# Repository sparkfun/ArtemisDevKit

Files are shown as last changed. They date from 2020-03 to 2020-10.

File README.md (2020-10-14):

SparkFun Artemis Development Kit
========================================

SparkFun Artemis Development Kit (https://www.sparkfun.com/products/16828)

* [*SparkFun Artemis Development Kit (DEV-16828)*](https://www.sparkfun.com/products/16828)
* [*SparkFun Artemis Development Kit with Camera (KIT-17071)*](https://www.sparkfun.com/products/17071)

The [*SparkFun Artemis Development Kit (DEV-16828)*](https://www.sparkfun.com/products/16828) is the latest board to be released around the SparkFun Artemis Module and it allows access to more software development features than previous Artemis based boards. Recommended software used to program the Artemis DK are the Arduino IDE, Arm® Mbed™ OS (Studio and CLI), and AmbiqSDK. An updated USB interface (MKL26Z128VFM4 Arm® Cortex®-M0+ MCU, from NXP) allows the Artemis Dev Kit to act as:

* Mass Storage Device (MSD): Used to provide drag and drop programming to the Artemis Module.
* Human Interface Device (HID): Used for the debugging interface to the Artemis Module.
* Communication Port (COM): Used to provide a serial communication UART between the Artemis and the USB connection (PC).

Repository Contents
-------------------

* **/Hardware**
   * Eagle design files (.brd, .sch)
   * Dimensions (.pdf and .png)
   * **/Production** - Production panel files (.brd)
* **/Reference**
   * Datasheets (.pdf)
   * Functional Block Digaram (.png)

Documentation
--------------
* [Hardware Getting Started Guide](https://learn.sparkfun.com/tutorials/1198) - Basic Hardware Guide for the Artemis DK
* Software Guides:
    * [Artemis Development with the Arduino IDE](https://learn.sparkfun.com/tutorials/artemis-development-with-the-arduino-ide) - A software guide for developing with the Artemis module (and related boards) in the Arduino IDE
    * [Artemis Development with Arm&reg; Mbed&trade; OS (Beta)](https://learn.sparkfun.com/tutorials/artemis-development-on-arm-mbed-os-beta) - A software pre-release guide to get started developing in with Mbed&trade; OS
    * Artemis Development with Arm&reg; Mbed&trade; OS (Pending release)
    * [Artemis Development with the AmbiqSDK](https://learn.sparkfun.com/tutorials/using-sparkfun-edge-board-with-ambiq-apollo3-sdk) - A software guide for utilizing the SparkFun Edge board with the AmbiqSDK
* [GitHub Repository for Apollo3 Board Support Packages (BSP)](https://github.com/sparkfun/SparkFun_Apollo3_AmbiqSuite_BSPs) - The Board Support Packages (BSPs) for SparkFun Apollo3 (Artemis) based boards to be used in the AmbiqSuite SDK
    * [ DAPLink Bootloader: `kl26z_artemis_dk_if.bin`](https://github.com/sparkfun/SparkFun_Apollo3_AmbiqSuite_BSPs/raw/master/artemis_dk/intfc/kl26z_bl.bin) - Underlying *bootloader* firmware for the MKL26Z MCU
    * [DAPLink Interface Firmware: `kl26z_bl.bin`](https://github.com/sparkfun/SparkFun_Apollo3_AmbiqSuite_BSPs/raw/master/artemis_dk/intfc/kl26z_artemis_dk_if.bin) - The accompanying *interface firmware* for the DAPLink debug probes from the MKL26Z to the target Artemis Module
* Development Software:
    * [SparkFun Ambiq Apollo3 Arduino Core](https://github.com/sparkfun/Arduino_Apollo3) - The SparkFun Arduino core for the Apollo3 MCU (i.e. the Artemis modules)
        * `.json` file needed for the SparkFun Ambiq Apollo3 Arduino Core:
        <br>
            <code><a href="https://raw.githubusercontent.com/sparkfun/Arduino_Apollo3/master/package_sparkfun_apollo3_index.json">https://raw.githubusercontent.com/sparkfun/Arduino_Apollo3/master/package_sparkfun_apollo3_index.json</a></code>
    * [Mbed™ OS](https://github.com/sparkfun/mbed-os-ambiq-apollo3) - Implementation of the Apollo3 (i.e. Artemis module) in Mbed&trade; OS
    * [AmbiqSDK](https://github.com/sparkfun/AmbiqSuiteSDK) - A copy of the AmbiqSuite SDK maintained by SparkFun
    * [pyOCD](https://github.com/sparkfun/pyOCD) - Implementation of the Apollo3 (i.e. Artemis module) for pyOCD
* Arduino Libraries:
    * [SparkFun LIS2DH12 Arduino Library](https://github.com/sparkfun/SparkFun_LIS2DH12_Arduino_Library) - The Arduino library for the accelerometer
    * [ArduinoBLE Library](https://github.com/arduino-libraries/ArduinoBLE) - The Arduino library for the BLE support

Product Versions
----------------
* [*SparkFun Artemis Development Kit with Camera (KIT-17071)*](https://www.sparkfun.com/products/17071) - v1.0 Initial Release *(kitted with Himax Camera)*
* [*SparkFun Artemis Development Kit (DEV-16828)*](https://www.sparkfun.com/products/16828) - v1.0 Initial Release

License Information
-------------------

This product is _**open source**_! 

Please review the LICENSE.md file for license information. 

If you have any questions or concerns on licensing, please contact technical support on our [SparkFun forums](https://forum.sparkfun.com/viewforum.php?f=152).

Distributed as-is; no warranty is given.

- Your friends at SparkFun.

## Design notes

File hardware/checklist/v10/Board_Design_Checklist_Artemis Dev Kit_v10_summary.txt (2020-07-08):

1) Does the board pass the Board Autochecklist ULP? [NO]
comment: footprint silk for SWD connectors, no standoffs (intentional), header spacing check is thrown off by addtl. PTH headers

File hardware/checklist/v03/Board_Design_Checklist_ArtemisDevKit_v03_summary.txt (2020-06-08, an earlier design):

1) Are the standoffs in the lower right corner? [NO]
comment: This design has no standoffs (could change for Reds)

2) Does the board pass the Board Autochecklist ULP? [NO]
comment: fails on standoffs (intentional), breadboard spacing (intentional, and not totally accurate) and footprint silk width (eagle library needs updating)

3) Do V-Scored edges have a 50 mil border free of pads and parts (to prevent cracking on separation)? [NO]
comment: This is outdated. We routinely have pads within 50 mil of edges

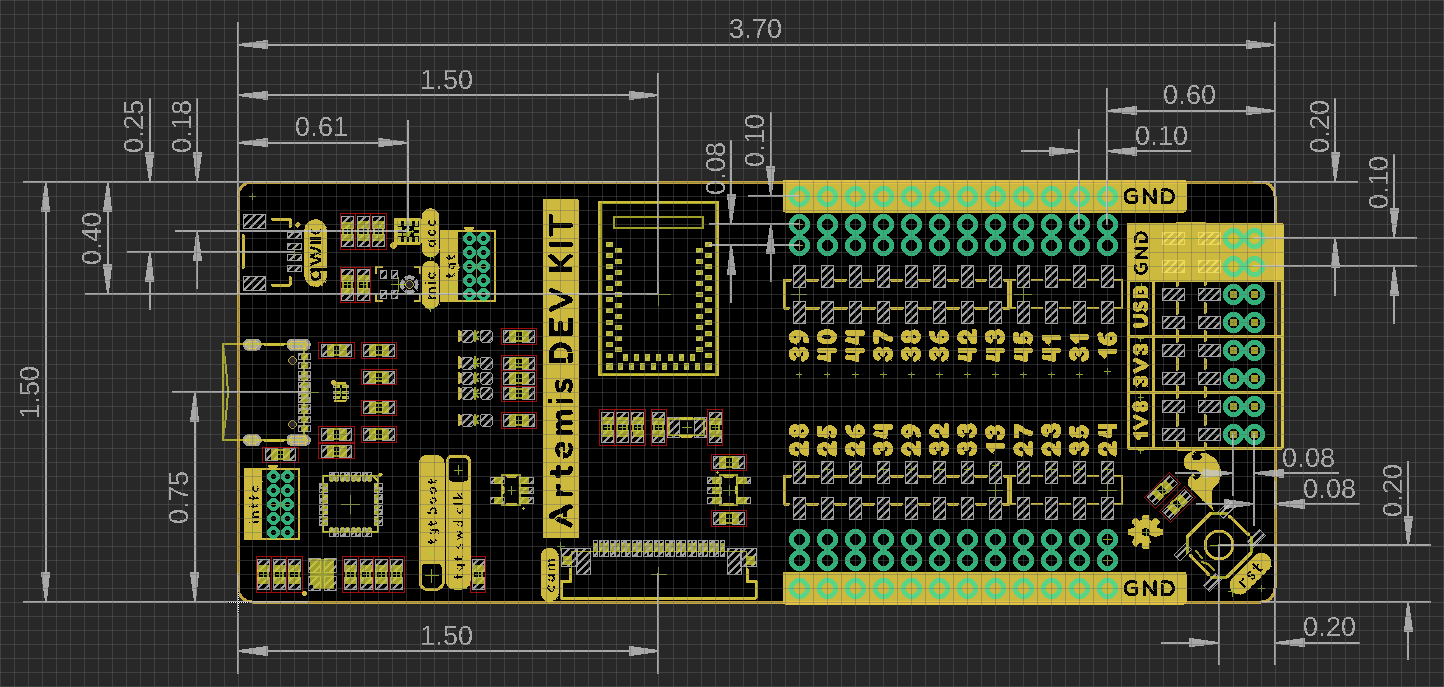
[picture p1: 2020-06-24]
hardware/board_dimensions.PNG

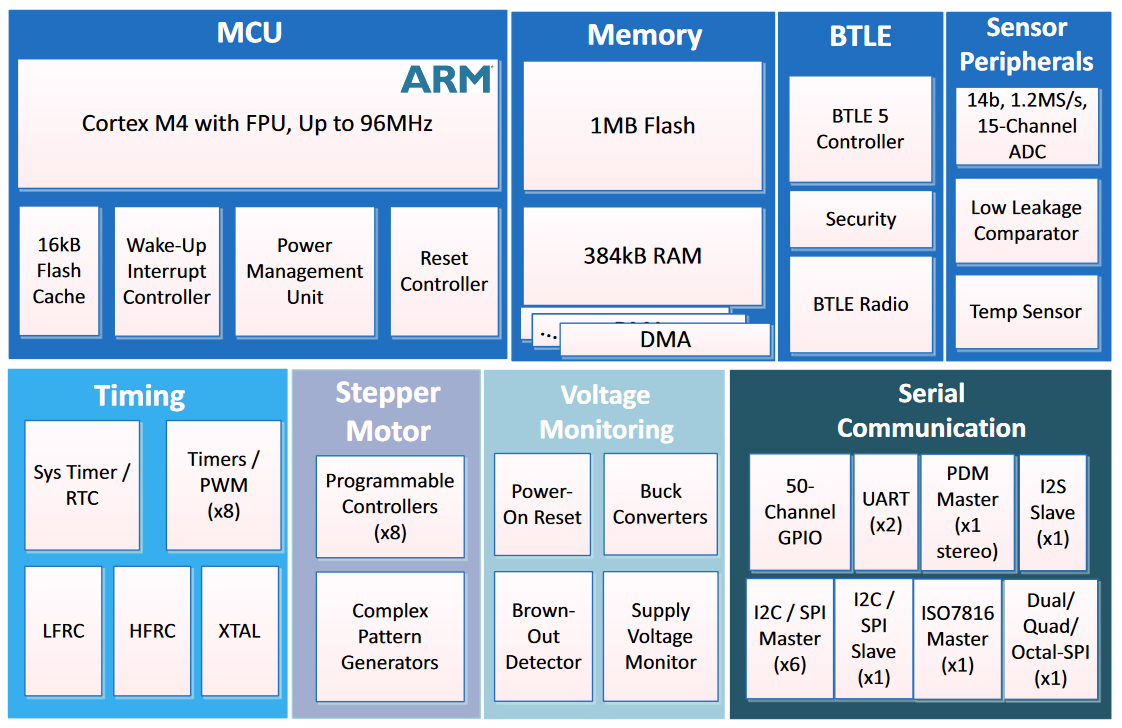
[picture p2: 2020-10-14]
reference/MCU_system_block_diagram.PNG

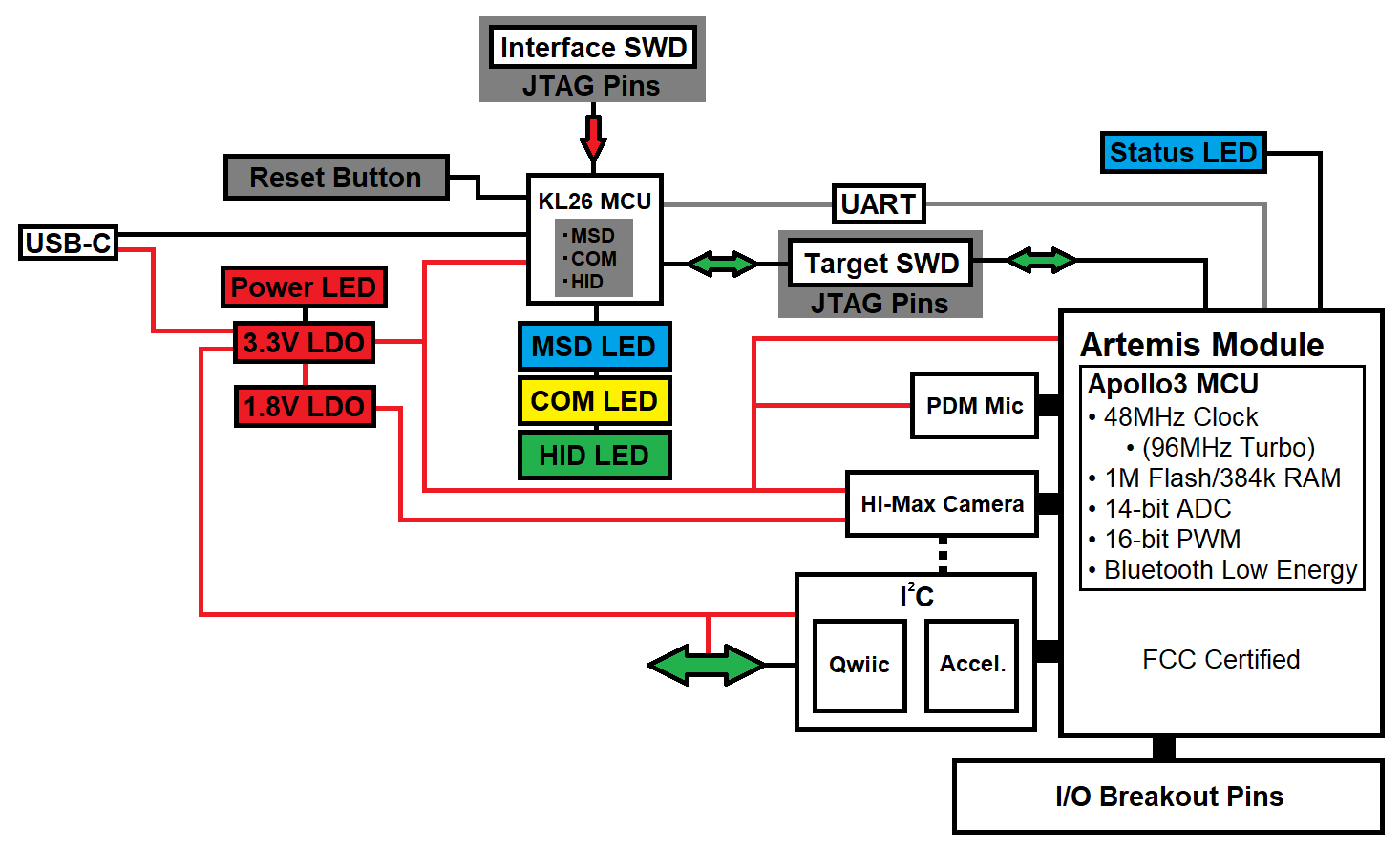
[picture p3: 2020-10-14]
reference/board_functional_block_diagram.png

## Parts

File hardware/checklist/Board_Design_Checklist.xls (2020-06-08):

SECTION | CHECK | STATUS | DEPENDANCY | CORRECT ANSWER | USER | USER-ANSWER | COMMENT | WIKI_LINK
Macro | is_revision | 0
Macro | has_pth | 0
Macro | has_i2c | 0
Macro | has_SPI | 0
Macro | has_1x6_ftdi_header | 0
Macro | has_jumpers | 0
Macro | has_leds | 0
Macro | has_vreg | 0
Macro | has_QFN | 0
Macro | has_SS | 0
Macro | has_multi_sheet | 0
Macro | is_kit | 0
Macro | has_serial | 0
Macro | is_4layer | 0
Macro | has_milling | 0
Macro | has_switchorbutton | 0
Macro | has_collaboration | 0
Schematic | Does the board pass the Schematic Autochecklist ULP? |  |  | YES
Schematic | Are all schematic objects inside the frame? |  |  | YES
Schematic | Is proper attribution given to the original designer? |  |  | YES
Schematic | Is "Revised by: " and the reviser's name present? |  | 2 | YES
Schematic | Have all nets been drawn straight out from pin connections at least one grid space? |  |  | YES
Schematic | Are there any 4-way junctions? |  |  | NO
Schematic | Are junction dots used for all 3-wire connections? |  |  | YES
Schematic | Are the fiducials in the lower right corner? |  |  | YES
Schematic | Are the standoffs in the lower right corner? |  |  | YES
Schematic | Are dashed grey lines ('info' eagle layer 97) used to clearly separate different areas? |  |  | YES
Schematic | Is the version number correct? |  |  | YES
Schematic | Is the version number included on all sheets? |  | 12 | YES
Schematic | Do all GND connections use the GND symbol (oriented downward)? |  |  | YES
Schematic | Do all VCC connections use the VCC symbol (oriented upward)? |  |  | YES
Schematic | Is the VCC range clearly labeled? |  |  | YES
Schematic | Are any jumpers labeled clearly by their function and possible settings? |  | 7 | YES
Schematic | Are any appropriate warnings (voltage conversion, sensitive I/O) labeled? |  |  | YES
Schematic | Are any notes of two versions of the board in the schematic (3.3V regulator vs 5V regulator)? |  |  | YES
Schematic | Do any part names have '/.~' in them? (Multiple sheets) |  | 12 | NO
Schematic | Have you verified that the BOM *including PCB* (also checking for PROD_ID, NAME, VALUE, PREFIX)? |  |  | YES
Schematic | Do any parts have unnecessary values (Eagle has autoset the package as the value)? |  |  | NO
Schematic | Regarding the voltage regulator, is the input on the LEFT, and the output on the RIGHT? |  | 9 | YES
Schematic | Is the I2C address in the schematic? |  | 4 | YES
Schematic | Is the I2C pin order correct (GND/VCC/SDA/CLK) and did you consider using a Qwiic connector? |  | 4 | YES |  |  |  | https://wiki.sparkfun.com/index.php?title=Eagle_Rules#Pin_Out.2FConnection_Orientation
Schematic | Is the I2C pull-up resistor isolation jumper present? |  | 4 | YES |  |  |  | https://wiki.sparkfun.com/index.php?title=Eagle_Rules#Component_Placement
Schematic | Is the SPI pull-up resistor for Chip Select present? |  | 5 | YES |  |  |  | https://wiki.sparkfun.com/index.php?title=Eagle_Rules#Component_Placement
Schematic | Is the MISO tri-state buffer included? |  | 5 | YES |  |  |  | https://wiki.sparkfun.com/index.php?title=Eagle_Rules#Component_Placement
Board | Does the board pass the Board Autochecklist ULP? |  |  | YES |  |  |  | https://wiki.sparkfun.com/index.php?title=Qwiic_Standard
Board | If this board is not branded as a Qwicc board, but contains a Qwiic connector, is the connector labeled with “QWIIC” text silk? |  | 4 | YES
Board | Are the inner layers on the correct eagle layers? (2 and 15) |  | 15 | YES |  |  |  | https://wiki.sparkfun.com/index.php?title=Eagle_Rules#Board_Creation.2C_Outline
Board | Does your 4 layer board include '1' '2' '3' '4' in the copper of each layer? |  | 15 | YES |  |  |  | https://wiki.sparkfun.com/index.php?title=Eagle_Rules#Board_Creation.2C_Outline
Board | If this is a Qwiic board, does it follow the design guidelines for Qwiic boards in the Wiki? |  | 4 | YES |  |  |  | https://wiki.sparkfun.com/index.php?title=Eagle_Rules#Board_Creation.2C_Outline
Board | If this requires very precise dimensions (e.g. USB stick), did you consider GP's tolerances? (dimension=5mils, Vscore=10mils) |  |  |  |  |  |  | https://wiki.sparkfun.com/index.php?title=Eagle_Rules#Fab_house_Tolerances
Board | Do all testpoints have a separation of at least 0.1 inch (preferably placed on a 0.05 inch grid)? |  |  | YES |  |  |  | https://wiki.sparkfun.com/index.php?title=Eagle_Rules#Board_Creation.2C_Outline
Board | Can standoffs/screws be used clear of other parts? |  |  | YES |  |  |  | https://wiki.sparkfun.com/index.php?title=Eagle_Rules#Board_Creation.2C_Outline
Board | Is the FTDI connector accessible (do neighboring parts allow enough space to clear each side)? |  | 6 | YES |  |  |  | https://wiki.sparkfun.com/index.php?title=Eagle_Rules#Pin_Out.2FConnection_Orientation
Board | Is the FTDI connector oriented so the FTDI breakout can be slid on properly (IC side up, header side down)? |  | 6 | YES |  |  |  | https://wiki.sparkfun.com/index.php?title=Eagle_Rules#Pin_Out.2FConnection_Orientation
Board | Are vias tented correctly? |  |  | YES |  |  |  | https://wiki.sparkfun.com/index.php?title=Eagle_Rules#Trace_Routing.2C_Polygon_Pours.2C_and_Vias
Board | If possible, are all overhanging parts on the same edge of the board (this helps with panelization)? |  |  | YES |  |  |  | https://wiki.sparkfun.com/index.php?title=Eagle_Rules#Pin_Out.2FConnection_Orientation
Board | If this design requires special ordering or production assembly instructions, have the symbols/packages been added with notes? (PCB thickness, humidity sensitivity, etc.) |  |  | YES
Board | Are any vias intended to be used as PTH headers (they shouldn't be)? |  |  | NO |  |  |  | https://wiki.sparkfun.com/index.php?title=Eagle_Rules#Trace_Routing.2C_Polygon_Pours.2C_and_Vias
Board | Is the LED color standard followed? (red for power, blue for STAT, green for TX, yellow for RX) |  | 8 | YES |  |  |  | https://wiki.sparkfun.com/index.php?title=Eagle_Rules#Component_Placement
Board | Do parts that need selective solder have a planned nozzle path on layer 48? (valid widths: 0.178", 0,263", 0.354") |  | 11 | YES |  |  |  | https://wiki.sparkfun.com/index.php?title=Eagle_Rules#Selective_Soldering
Board | As best as possible, do all SMD pads have only 1 trace entering the pad? |  |  | YES |  |  |  | https://wiki.sparkfun.com/index.php?title=Eagle_Rules#PCB_Layout
Board | Are there any natural bridges on SMT components? |  |  | NO |  |  |  | https://wiki.sparkfun.com/index.php?title=Eagle_Rules#PCB_Layout
Board | Do V-Scored edges have a 50 mil border free of pads and parts (to prevent cracking on separation)? |  |  | YES
Board | Is the direction of TX/RX serial connections correct? |  | 14 | YES
Board | Are the TX/RX pins of the FTDI properly connected? |  | 6 | YES
Board | Is trace routing up to spec? (to/from center-points, straight lines, 45 angles, 'T' intersections, no right angles or acid traps) |  |  | YES |  |  |  | https://wiki.sparkfun.com/index.php?title=Eagle_Rules#PCB_Layout
Board | For thermal considerations, are traces routed away from the component, with symmetrical routing? |  | 10 | YES
Board | Do all footprints pass 1:1 check? (Applies mostly to new components) |  |  | YES
Board | Are all QFN components with 6 or more leads 75 percent pasted on lead pads? (May be contended depending on performance) |  | 10 | YES |  |  |  | https://wiki.sparkfun.com/index.php?title=Eagle_Rules#Footprints.2FPackages
Board | Are center pad cream apertures properly reduced? (50-75% paste is good) |  | 10 | YES |  |  |  | https://wiki.sparkfun.com/index.php?title=Eagle_Rules#Footprints.2FPackages
Board | Is there solder mask between pads on of 11 mil separation and greater? |  |  | YES |  |  |  | https://wiki.sparkfun.com/index.php?title=Eagle_Rules#Fab_house_Tolerances
Board | Is there a correct version number in the copper (aligned properly with the edge of the PCB)? |  |  | YES
Board | Does it pass DRC with top/bottom keepout layers on? |  |  | YES
Board | If there are any DRC errors, have they all been approved? |  |  | YES
Board | Are all KIT PTH parts on the correct side with correct masking (e.g. the TSTOP or BSTOP expose the correct side) |  | 13 | YES
Documentation | Is there a note for a 4-layer board (on tDOCU)? |  | 15 | YES
Documentation | Do all packages have NAME and VALUE? |  |  | YES
Documentation | Is there a note for a board thickness other than 0.63 inch?
Documentation | Are measurements included for outer dimension and standoffs (Eagle layer 47)? |  |  | YES
Documentation | Are the board dimensions on 0.05 inch or 0.01 inch grid? |  |  | YES
Documentation | Are routed-out areas labeled 'ROUTE OUT' (on dimension)? |  | 16 | YES
Documentation | Is the designer name included in tDocu? |  |  | YES
Documentation | Is 'Revised by:' and 'Revisor Name' included in tDocu? |  | 2 | YES
Documentation | Are all Fuse Bits/ Lock Bits/ Config Words etc documented on the Github Readme? |  |  | YES
Silkscreen/Labeling | Is the name of the board on the board? |  |  | YES |  |  |  | https://wiki.sparkfun.com/index.php?title=Eagle_Rules#PCB_Silk
Silkscreen/Labeling | Are all LEDs labeled with their purpose? |  | 8 | YES
Silkscreen/Labeling | Are all PTHs (aka connectors) clearly labeled with their purpose on both sides of the board? |  |  | YES
Silkscreen/Labeling | Are battery terminals labeled +/- correctly? |  |  | YES
Silkscreen/Labeling | Are all jumpers labeled? |  | 7 | YES
Silkscreen/Labeling | If it is a 3-way jumper, is there a label on each side of the jumper? |  | 7 | YES
Silkscreen/Labeling | Are all switches/buttons labeled properly? |  | 17 | YES
Silkscreen/Labeling | Are active low pins labeled clearly? |  |  | YES
Silkscreen/Labeling | Are all labels lined up properly and legible? |  |  | YES
Silkscreen/Labeling | Does the FTDI connector have BLK/GRN labeled correctly? |  | 6 | YES
Silkscreen/Labeling | Do all components have polarity or pin 1 labeled? |  |  | YES
Silkscreen/Labeling | Is the polarity label outside of the package for visibility after part population? |  |  | YES
Silkscreen/Labeling | Are there check labels for different versions of the board (3.3V vs 5V)? |  |  | YES
Silkscreen/Labeling | Is the firmware opensource? If not, did you omit the OSHW Logo? |  | 18 | YES
Silkscreen/Labeling | Is any silkscreen overlaid on vias? |  |  | NO
Silkscreen/Labeling | Is there a URL for any kits or unique boards?
Special | Are dimension lines properly spaced for V-scoring (lines on a 0.020” center-to-center spacing)?
Special | On white solder mask pcbs, is there any solder mask between leads on large SMT components?
Special | Are axes labeled correctly?
Special | Are there warning labels for high voltage areas?
END | Thanks for flying with us. Have a great day!!

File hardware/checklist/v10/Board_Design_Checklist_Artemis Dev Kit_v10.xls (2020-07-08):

SECTION | CHECK | STATUS | DEPENDANCY | CORRECT ANSWER | USER | USER-ANSWER | COMMENT | WIKI_LINK
Macro | is_revision | 0
Macro | has_pth | 0
Macro | has_i2c | 1
Macro | has_SPI | 1
Macro | has_1x6_ftdi_header | 0
Macro | has_jumpers | 1
Macro | has_leds | 1
Macro | has_vreg | 1
Macro | has_QFN | 0
Macro | has_SS | 0
Macro | has_multi_sheet | 0
Macro | is_kit | 0
Macro | has_serial | 1
Macro | is_4layer | 0
Macro | has_milling | 0
Macro | has_switchorbutton | 1
Macro | has_collaboration | 1
Schematic | Does the board pass the Schematic Autochecklist ULP? |  |  | YES | Lyocek | YES
Schematic | Are all schematic objects inside the frame? |  |  | YES | Lyocek | YES
Schematic | Is proper attribution given to the original designer? |  |  | YES | Lyocek | YES
Schematic | Is "Revised by: " and the reviser's name present? |  | 2 | YES | Lyocek | *n/a*
Schematic | Have all nets been drawn straight out from pin connections at least one grid space? |  |  | YES | Lyocek | YES
Schematic | Are there any 4-way junctions? |  |  | NO | Lyocek | NO
Schematic | Are junction dots used for all 3-wire connections? |  |  | YES | Lyocek | YES
Schematic | Are the fiducials in the lower right corner? |  |  | YES | Lyocek | YES
Schematic | Are the standoffs in the lower right corner? |  |  | YES | Lyocek | n/a
Schematic | Are dashed grey lines ('info' eagle layer 97) used to clearly separate different areas? |  |  | YES | Lyocek | YES
Schematic | Is the version number correct? |  |  | YES | Lyocek | YES
Schematic | Is the version number included on all sheets? |  | 12 | YES | Lyocek | *n/a*
Schematic | Do all GND connections use the GND symbol (oriented downward)? |  |  | YES | Lyocek | YES
Schematic | Do all VCC connections use the VCC symbol (oriented upward)? |  |  | YES | Lyocek | YES
Schematic | Is the VCC range clearly labeled? |  |  | YES | Lyocek | YES
Schematic | Are any jumpers labeled clearly by their function and possible settings? |  | 7 | YES | Lyocek | YES
Schematic | Are any appropriate warnings (voltage conversion, sensitive I/O) labeled? |  |  | YES | Lyocek | n/a
Schematic | Are any notes of two versions of the board in the schematic (3.3V regulator vs 5V regulator)? |  |  | YES | Lyocek | n/a
Schematic | Do any part names have '/.~' in them? (Multiple sheets) |  | 12 | NO | Lyocek | *n/a*
Schematic | Have you verified that the BOM *including PCB* (also checking for PROD_ID, NAME, VALUE, PREFIX)? |  |  | YES | Lyocek | YES
Schematic | Do any parts have unnecessary values (Eagle has autoset the package as the value)? |  |  | NO | Lyocek | NO
Schematic | Regarding the voltage regulator, is the input on the LEFT, and the output on the RIGHT? |  | 9 | YES | Lyocek | YES
Schematic | Is the I2C address in the schematic? |  | 4 | YES | Lyocek | n/a
Schematic | Is the I2C pin order correct (GND/VCC/SDA/CLK) and did you consider using a Qwiic connector? |  | 4 | YES | Lyocek | YES |  | https://wiki.sparkfun.com/index.php?title=Eagle_Rules#Pin_Out.2FConnection_Orientation
Schematic | Is the I2C pull-up resistor isolation jumper present? |  | 4 | YES | Lyocek | n/a |  | https://wiki.sparkfun.com/index.php?title=Eagle_Rules#Component_Placement
Schematic | Is the SPI pull-up resistor for Chip Select present? |  | 5 | YES | Lyocek | n/a |  | https://wiki.sparkfun.com/index.php?title=Eagle_Rules#Component_Placement
Schematic | Is the MISO tri-state buffer included? |  | 5 | YES | Lyocek | n/a |  | https://wiki.sparkfun.com/index.php?title=Eagle_Rules#Component_Placement
Board | Does the board pass the Board Autochecklist ULP? |  |  | YES | Lyocek | NO | footprint silk for SWD connectors, no standoffs (intentional), header spacing check is thrown off by addtl. PTH headers | https://wiki.sparkfun.com/index.php?title=Qwiic_Standard
Board | If this board is not branded as a Qwicc board, but contains a Qwiic connector, is the connector labeled with “QWIIC” text silk? |  | 4 | YES | Lyocek | YES
Board | Are the inner layers on the correct eagle layers? (2 and 15) |  | 15 | YES | Lyocek | *n/a* |  | https://wiki.sparkfun.com/index.php?title=Eagle_Rules#Board_Creation.2C_Outline
Board | Does your 4 layer board include '1' '2' '3' '4' in the copper of each layer? |  | 15 | YES | Lyocek | *n/a* |  | https://wiki.sparkfun.com/index.php?title=Eagle_Rules#Board_Creation.2C_Outline
Board | If this is a Qwiic board, does it follow the design guidelines for Qwiic boards in the Wiki? |  | 4 | YES | Lyocek | n/a |  | https://wiki.sparkfun.com/index.php?title=Eagle_Rules#Board_Creation.2C_Outline
Board | If this requires very precise dimensions (e.g. USB stick), did you consider GP's tolerances? (dimension=5mils, Vscore=10mils) |  |  |  | Lyocek | n/a |  | https://wiki.sparkfun.com/index.php?title=Eagle_Rules#Fab_house_Tolerances
Board | Do all testpoints have a separation of at least 0.1 inch (preferably placed on a 0.05 inch grid)? |  |  | YES | Lyocek | YES |  | https://wiki.sparkfun.com/index.php?title=Eagle_Rules#Board_Creation.2C_Outline
Board | Can standoffs/screws be used clear of other parts? |  |  | YES | Lyocek | n/a |  | https://wiki.sparkfun.com/index.php?title=Eagle_Rules#Board_Creation.2C_Outline
Board | Is the FTDI connector accessible (do neighboring parts allow enough space to clear each side)? |  | 6 | YES | Lyocek | *n/a* |  | https://wiki.sparkfun.com/index.php?title=Eagle_Rules#Pin_Out.2FConnection_Orientation
Board | Is the FTDI connector oriented so the FTDI breakout can be slid on properly (IC side up, header side down)? |  | 6 | YES | Lyocek | *n/a* |  | https://wiki.sparkfun.com/index.php?title=Eagle_Rules#Pin_Out.2FConnection_Orientation
Board | Are vias tented correctly? |  |  | YES | Lyocek | YES |  | https://wiki.sparkfun.com/index.php?title=Eagle_Rules#Trace_Routing.2C_Polygon_Pours.2C_and_Vias
Board | If possible, are all overhanging parts on the same edge of the board (this helps with panelization)? |  |  | YES | Lyocek | YES |  | https://wiki.sparkfun.com/index.php?title=Eagle_Rules#Pin_Out.2FConnection_Orientation
Board | If this design requires special ordering or production assembly instructions, have the symbols/packages been added with notes? (PCB thickness, humidity sensitivity, etc.) |  |  | YES | Lyocek | n/a
Board | Are any vias intended to be used as PTH headers (they shouldn't be)? |  |  | NO | Lyocek | NO |  | https://wiki.sparkfun.com/index.php?title=Eagle_Rules#Trace_Routing.2C_Polygon_Pours.2C_and_Vias
Board | Is the LED color standard followed? (red for power, blue for STAT, green for TX, yellow for RX) |  | 8 | YES | Lyocek | YES |  | https://wiki.sparkfun.com/index.php?title=Eagle_Rules#Component_Placement
Board | Do parts that need selective solder have a planned nozzle path on layer 48? (valid widths: 0.178", 0,263", 0.354") |  | 11 | YES | Lyocek | *n/a* |  | https://wiki.sparkfun.com/index.php?title=Eagle_Rules#Selective_Soldering
Board | As best as possible, do all SMD pads have only 1 trace entering the pad? |  |  | YES | Lyocek | YES |  | https://wiki.sparkfun.com/index.php?title=Eagle_Rules#PCB_Layout
Board | Are there any natural bridges on SMT components? |  |  | NO | Lyocek | NO |  | https://wiki.sparkfun.com/index.php?title=Eagle_Rules#PCB_Layout
Board | Do V-Scored edges have a 50 mil border free of pads and parts (to prevent cracking on separation)? |  |  | YES | Lyocek | YES
Board | Is the direction of TX/RX serial connections correct? |  | 14 | YES | Lyocek | YES
Board | Are the TX/RX pins of the FTDI properly connected? |  | 6 | YES | Lyocek | *n/a*
Board | Is trace routing up to spec? (to/from center-points, straight lines, 45 angles, 'T' intersections, no right angles or acid traps) |  |  | YES | Lyocek | YES |  | https://wiki.sparkfun.com/index.php?title=Eagle_Rules#PCB_Layout
Board | For thermal considerations, are traces routed away from the component, with symmetrical routing? |  | 10 | YES | Lyocek | *n/a*
Board | Do all footprints pass 1:1 check? (Applies mostly to new components) |  |  | YES | Lyocek | YES
Board | Are all QFN components with 6 or more leads 75 percent pasted on lead pads? (May be contended depending on performance) |  | 10 | YES | Lyocek | *n/a* |  | https://wiki.sparkfun.com/index.php?title=Eagle_Rules#Footprints.2FPackages
Board | Are center pad cream apertures properly reduced? (50-75% paste is good) |  | 10 | YES | Lyocek | *n/a* |  | https://wiki.sparkfun.com/index.php?title=Eagle_Rules#Footprints.2FPackages
Board | Is there solder mask between pads on of 11 mil separation and greater? |  |  | YES | Lyocek | YES |  | https://wiki.sparkfun.com/index.php?title=Eagle_Rules#Fab_house_Tolerances
Board | Is there a correct version number in the copper (aligned properly with the edge of the PCB)? |  |  | YES | Lyocek | YES
Board | Does it pass DRC with top/bottom keepout layers on? |  |  | YES | Lyocek | YES
Board | If there are any DRC errors, have they all been approved? |  |  | YES | Lyocek | YES
Board | Are all KIT PTH parts on the correct side with correct masking (e.g. the TSTOP or BSTOP expose the correct side) |  | 13 | YES | Lyocek | *n/a*
Documentation | Is there a note for a 4-layer board (on tDOCU)? |  | 15 | YES | Lyocek | *n/a*
Documentation | Do all packages have NAME and VALUE? |  |  | YES | Lyocek | YES
Documentation | Is there a note for a board thickness other than 0.63 inch? |  |  |  | Lyocek | n/a
Documentation | Are measurements included for outer dimension and standoffs (Eagle layer 47)? |  |  | YES | Lyocek | YES
Documentation | Are the board dimensions on 0.05 inch or 0.01 inch grid? |  |  | YES | Lyocek | YES
Documentation | Are routed-out areas labeled 'ROUTE OUT' (on dimension)? |  | 16 | YES | Lyocek | *n/a*
Documentation | Is the designer name included in tDocu? |  |  | YES | Lyocek | YES
Documentation | Is 'Revised by:' and 'Revisor Name' included in tDocu? |  | 2 | YES | Lyocek | *n/a*
Documentation | Are all Fuse Bits/ Lock Bits/ Config Words etc documented on the Github Readme? |  |  | YES | Lyocek | n/a
Silkscreen/Labeling | Is the name of the board on the board? |  |  | YES | Lyocek | YES |  | https://wiki.sparkfun.com/index.php?title=Eagle_Rules#PCB_Silk
Silkscreen/Labeling | Are all LEDs labeled with their purpose? |  | 8 | YES | Lyocek | YES
Silkscreen/Labeling | Are all PTHs (aka connectors) clearly labeled with their purpose on both sides of the board? |  |  | YES | Lyocek | YES
Silkscreen/Labeling | Are battery terminals labeled +/- correctly? |  |  | YES | Lyocek | n/a
Silkscreen/Labeling | Are all jumpers labeled? |  | 7 | YES | Lyocek | YES
Silkscreen/Labeling | If it is a 3-way jumper, is there a label on each side of the jumper? |  | 7 | YES | Lyocek | n/a
Silkscreen/Labeling | Are all switches/buttons labeled properly? |  | 17 | YES | Lyocek | YES
Silkscreen/Labeling | Are active low pins labeled clearly? |  |  | YES | Lyocek | YES
Silkscreen/Labeling | Are all labels lined up properly and legible? |  |  | YES | Lyocek | YES
Silkscreen/Labeling | Does the FTDI connector have BLK/GRN labeled correctly? |  | 6 | YES | Lyocek | *n/a*
Silkscreen/Labeling | Do all components have polarity or pin 1 labeled? |  |  | YES | Lyocek | YES
Silkscreen/Labeling | Is the polarity label outside of the package for visibility after part population? |  |  | YES | Lyocek | YES
Silkscreen/Labeling | Are there check labels for different versions of the board (3.3V vs 5V)? |  |  | YES | Lyocek | n/a
Silkscreen/Labeling | Is the firmware opensource? If not, did you omit the OSHW Logo? |  | 18 | YES | Lyocek | YES
Silkscreen/Labeling | Is any silkscreen overlaid on vias? |  |  | NO | Lyocek | YES
Silkscreen/Labeling | Is there a URL for any kits or unique boards? |  |  |  | Lyocek | n/a
Special | Are dimension lines properly spaced for V-scoring (lines on a 0.020” center-to-center spacing)? |  |  |  | Lyocek | YES
Special | On white solder mask pcbs, is there any solder mask between leads on large SMT components? |  |  |  | Lyocek | n/a
Special | Are axes labeled correctly? |  |  |  | Lyocek | YES
Special | Are there warning labels for high voltage areas? |  |  |  | Lyocek | n/a
END | Thanks for flying with us. Have a great day!! |  |  |  | Lyocek | NO

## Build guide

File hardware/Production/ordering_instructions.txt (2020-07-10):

panel size, 113x161mm
PCB thickness, 1.6mm
number of layers, 2
soldermask color, Red
silkscreen color, White
oz copper, 1oz
finish, HASL lead free
stencils, top+bottom
pcs per panel, 4
min trace width, 0.2032mm / 0.0080in
min drill size, 0.3810mm / 0.0150in

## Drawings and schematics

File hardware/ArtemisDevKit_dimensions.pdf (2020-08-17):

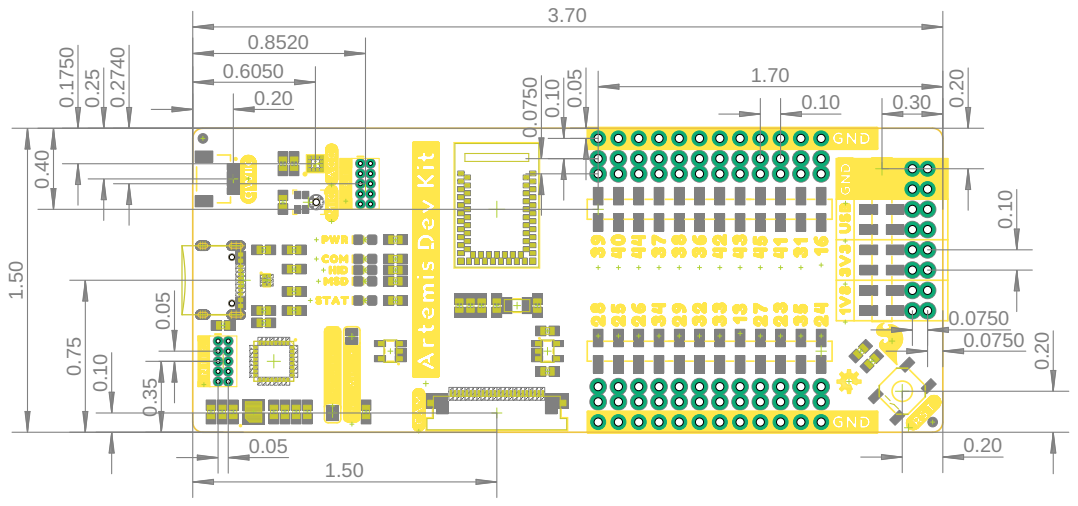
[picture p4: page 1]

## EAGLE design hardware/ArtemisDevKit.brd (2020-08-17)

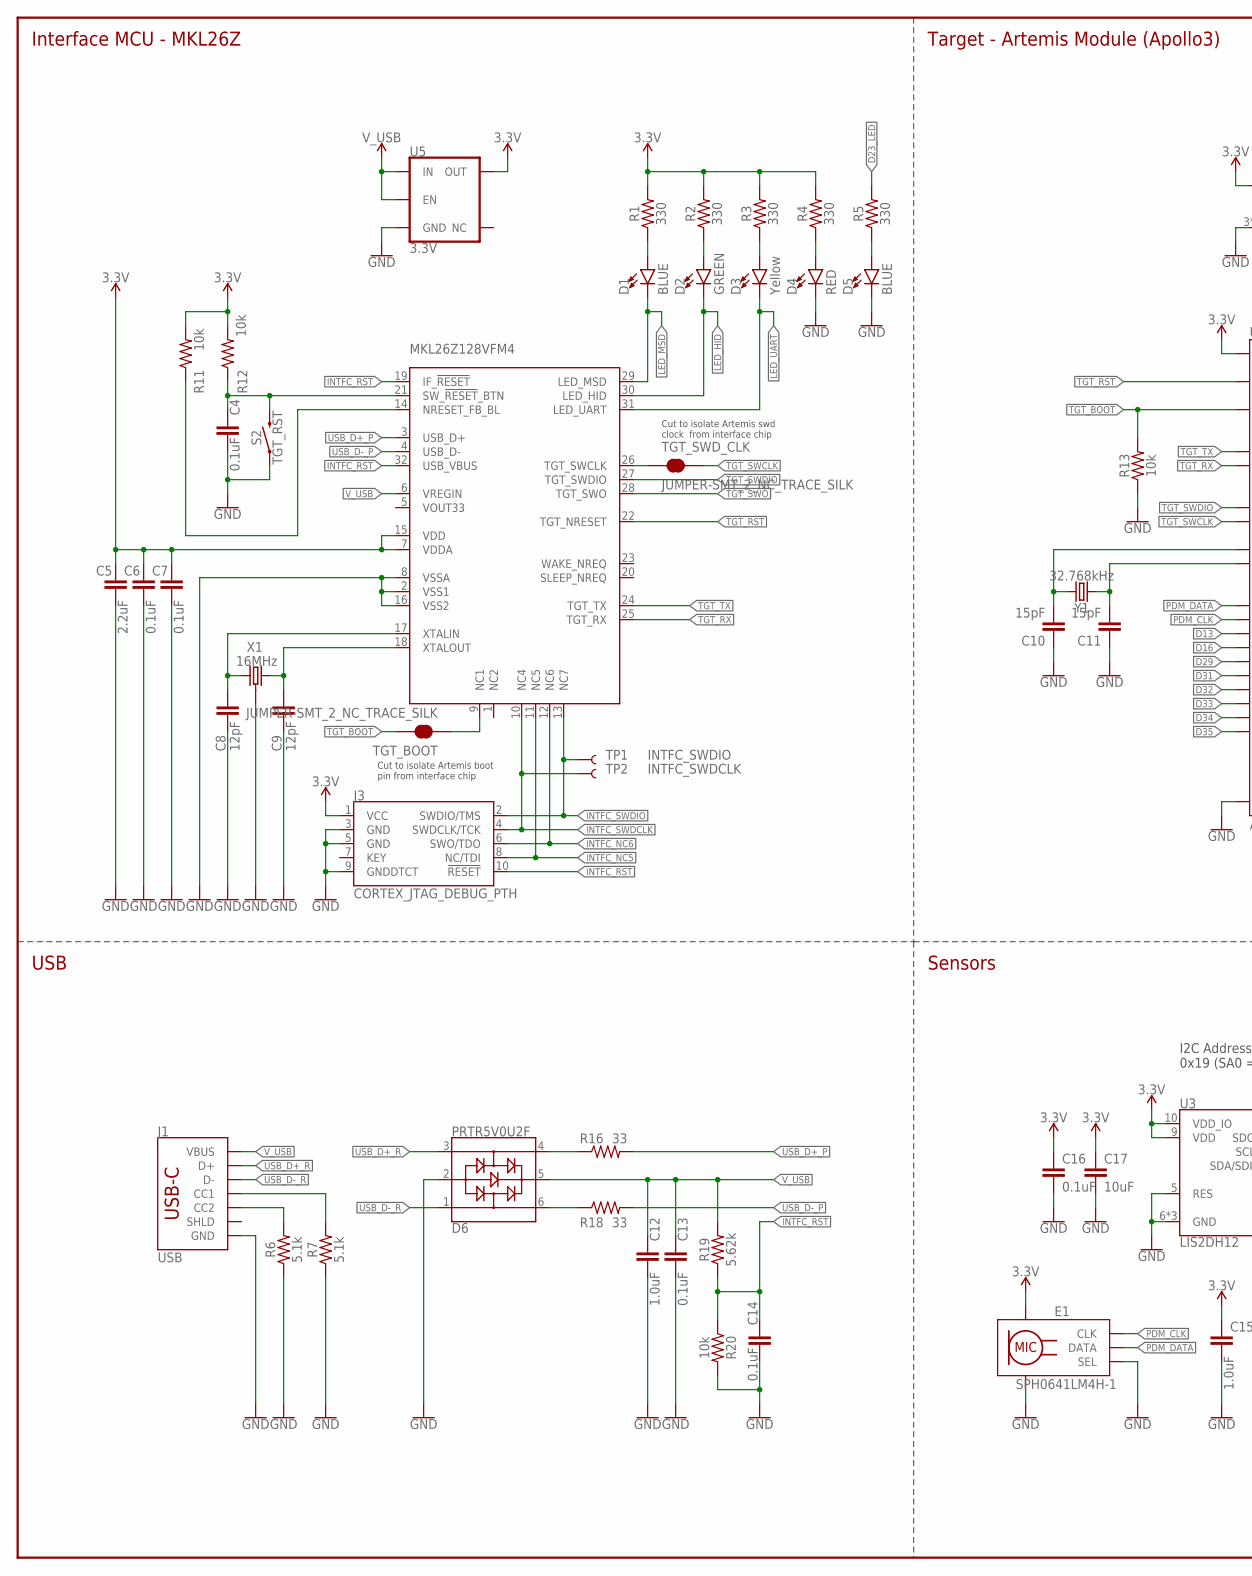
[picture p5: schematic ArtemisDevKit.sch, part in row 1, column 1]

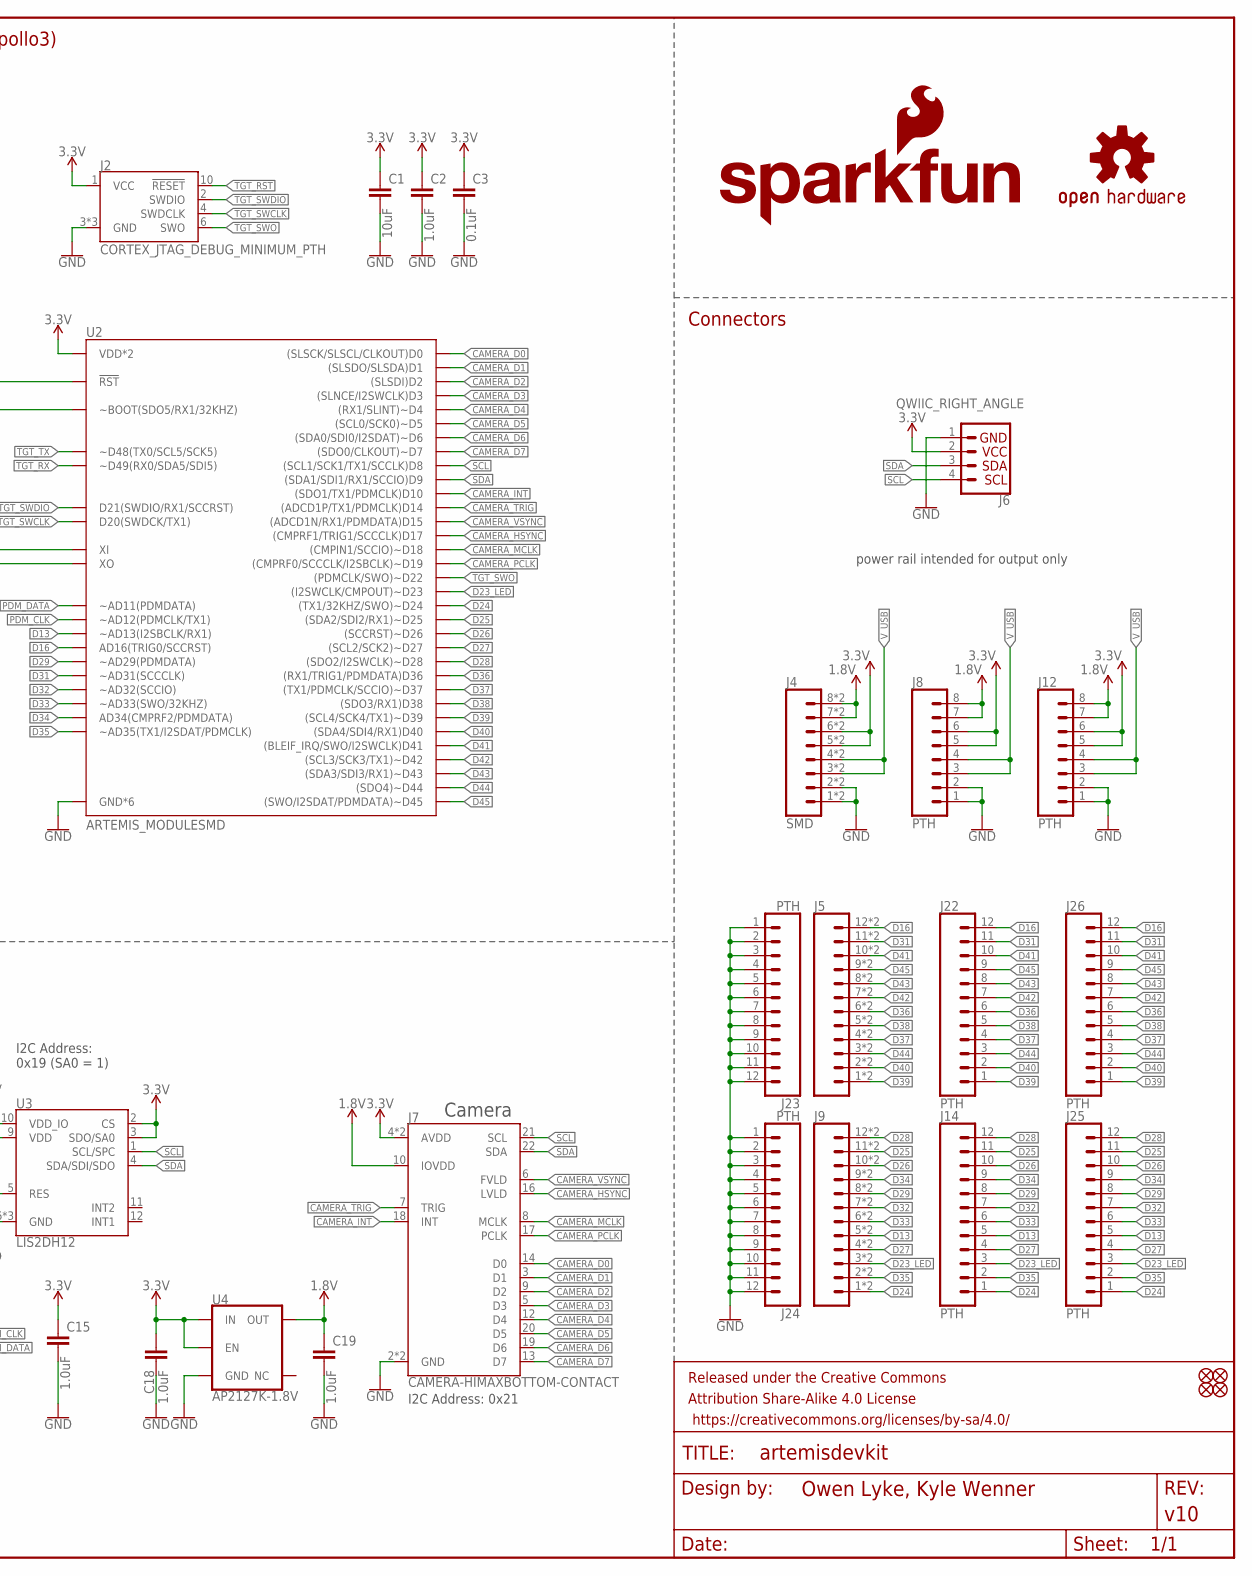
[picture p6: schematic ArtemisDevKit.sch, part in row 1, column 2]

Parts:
C1, C17: 10uF; 0603
C2, C12, C15, C18, C19: 1.0uF; 0603
C3, C4, C6, C7, C13, C14, C16: 0.1uF; 0603
C5: 2.2uF; 0603
C8, C9: 12pF; 0603
C10, C11: 15pF; 0603
D1, D5: BLUE; LED-0603
D2: GREEN; LED-0603
D3: Yellow; LED-0603
D4: RED; LED-0603
D6: PRTR5V0U2F; SOT886
E1: SPH0641LM4H-1; SPH0641LM4H-1_MICROPHONE
FD1, FD2, FD3, FD4: FIDUCIAL1X2; FIDUCIAL-1X2
FRAME1: FRAME-LEDGER; CREATIVE_COMMONS
J1: USB; USB-C-16P
J2: CORTEX_JTAG_DEBUG_MINIMUM_PTH; 2X5-PTH-1.27MM
J3: CORTEX_JTAG_DEBUG_PTH; 2X5-PTH-1.27MM
J4: SMD; 1X08_SMD_COMBINED
J5, J9: CONN_12SMD_COMBINED; 1X12_SMD_COMBINED
J6: QWIIC_RIGHT_ANGLE; JST04_1MM_RA
J7: CAMERA-HIMAXBOTTOM-CONTACT; FPC-24-AMPHENOL-SFV24R-1STE1HLF
J8, J12: PTH; 1X08_NO_SILK
J14, J22, J23, J24, J25, J26: PTH; 1X12_NO_SILK
LOGO1: OSHW-LOGOS; OSHW-LOGO-S
LOGO2: SFE_LOGO_NAME_FLAME.2_INCH; SFE_LOGO_NAME_FLAME_.2
R1, R2, R3, R4, R5: 330; 0603
R6, R7: 5.1k; 0603
R11, R12, R13, R20: 10k; 0603
R16, R18: 33; 0603
R19: 5.62k; 0603
S2: TGT_RST; TACTILE_SWITCH_SMD_5.2MM
TGT_BOOT: JUMPER-SMT_2_NC_TRACE_SILK; SMT-JUMPER_2_NC_TRACE_SILK
TGT_SWD_CLK: JUMPER-SMT_2_NC_TRACE_SILK; SMT-JUMPER_2_NC_TRACE_SILK
TP1: INTFC_SWDIO; PAD.03X.03
TP2: INTFC_SWDCLK; PAD.03X.03
U1: DAPLINK_KL26Z128VFM4; QFN-32-NOPAD
U2: ARTEMIS_MODULESMD; ARTEMIS_FP
U3: LIS2DH12; LGA-12-LISDH12
U4: AP2127K-1.8V; SOT23-5
U5: 3.3V; SOT23-5
X1: 16MHz; CRYSTAL-SMD-2X2.5MM
Y1: 32.768kHz; CRYSTAL-SMD-3.2X1.5MM

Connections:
1.8V: C19.1, J4.7, J4.7@2 (7), J4.8, J4.8@2 (8), J7.10 (IOVDD), J8.7, J8.8, J12.7, J12.8, U4.5 (OUT)
3.3V: C1.1, C2.1, C3.1, C5.1, C6.1, C7.1, C15.1, C16.1, C17.1, C18.1, E1.5 (VDD), J2.1 (VCC), J3.1 (VCC), J4.5, J4.5@2 (5), J4.6, J4.6@2 (6), J6.2, J7.4 (AVDD), J7.11 (AVDD), J8.5, J8.6, J12.5, J12.6, R1.2, R2.2, R3.2, R4.2, R11.2, R12.2, U1.7 (VDDA), U1.15 (VDD), U2.VDD@36 (VDD*2), U2.VDD@37 (VDD*2), U3.2 (CS), U3.3 (SDO/SA0), U3.9 (VDD), U3.10 (VDD_IO), U4.1 (IN), U4.3 (EN), U5.5 (OUT)
!INTFC_RST: C14.1, J3.10 (!RESET), R19.1, R20.1, U1.19 (IF_!RESET), U1.32 (USB_VBUS)
!RST!_BTN: C4.1, R12.1, S2.3 (2), U1.21 (SW_!RESET!_BTN)
!TGT_RST: J2.10 (!RESET), U1.22 (TGT_NRESET), U2.~RST (!RST)
CAMERA_D0: J7.14 (D0), U2.D0 ((SLSCK/SLSCL/CLKOUT)D0)
CAMERA_D1: J7.3 (D1), U2.D1 ((SLSDO/SLSDA)D1)
CAMERA_D2: J7.9 (D2), U2.D2 ((SLSDI)D2)
CAMERA_D3: J7.5 (D3), U2.D3 ((SLNCE/I2SWCLK)D3)
CAMERA_D4: J7.12 (D4), U2.~D4 ((RX1/SLINT)~D4)
CAMERA_D5: J7.20 (D5), U2.~D5 ((SCL0/SCK0)~D5)
CAMERA_D6: J7.19 (D6), U2.~D6 ((SDA0/SDI0/I2SDAT)~D6)
CAMERA_D7: J7.13 (D7), U2.D7 ((SDO0/CLKOUT)~D7)
CAMERA_HSYNC: J7.16 (LVLD), U2.D17 ((CMPRF1/TRIG1/SCCCLK)D17)
CAMERA_INT: J7.18 (INT), U2.D10 ((SDO1/TX1/PDMCLK)D10)
CAMERA_MCLK: J7.8 (MCLK), U2.~D18 ((CMPIN1/SCCIO)~D18)
CAMERA_PCLK: J7.17 (PCLK), U2.~D19 ((CMPRF0/SCCCLK/I2SBCLK)~D19)
CAMERA_TRIG: J7.7 (TRIG), U2.D14 ((ADCD1P/TX1/PDMCLK)D14)
CAMERA_VSYNC: J7.6 (FVLD), U2.D15 ((ADCD1N/RX1/PDMDATA)D15)
D13: J9.5, J9.5@2 (5), J14.5, J25.5, U2.~AD13 (~AD13(I2SBCLK/RX1))
D16: J5.12, J5.12@2 (12), J22.12, J26.12, U2.AD16 (AD16(TRIG0/SCCRST))
D23_LED: J9.3, J9.3@2 (3), J14.3, J25.3, R5.2, U2.~D23 ((I2SWCLK/CMPOUT)~D23)
D24: J9.1, J9.1@2 (1), J14.1, J25.1, U2.~D24 ((TX1/32KHZ/SWO)~D24)
D25: J9.11, J9.11@2 (11), J14.11, J25.11, U2.~D25 ((SDA2/SDI2/RX1)~D25)
D26: J9.10, J9.10@2 (10), J14.10, J25.10, U2.~D26 ((SCCRST)~D26)
D27: J9.4, J9.4@2 (4), J14.4, J25.4, U2.~D27 ((SCL2/SCK2)~D27)
D28: J9.12, J9.12@2 (12), J14.12, J25.12, U2.~D28 ((SDO2/I2SWCLK)~D28)
D29: J9.8, J9.8@2 (8), J14.8, J25.8, U2.~AD29 (~AD29(PDMDATA))
D31: J5.11, J5.11@2 (11), J22.11, J26.11, U2.~AD31 (~AD31(SCCCLK))
D32: J9.7, J9.7@2 (7), J14.7, J25.7, U2.~AD32 (~AD32(SCCIO))
D33: J9.6, J9.6@2 (6), J14.6, J25.6, U2.~AD33/SWO (~AD33(SWO/32KHZ))
D34: J9.9, J9.9@2 (9), J14.9, J25.9, U2.AD34 (AD34(CMPRF2/PDMDATA))
D35: J9.2, J9.2@2 (2), J14.2, J25.2, U2.~AD35 (~AD35(TX1/I2SDAT/PDMCLK))
D36: J5.6, J5.6@2 (6), J22.6, J26.6, U2.D36 ((RX1/TRIG1/PDMDATA)D36)
D37: J5.4, J5.4@2 (4), J22.4, J26.4, U2.~D37 ((TX1/PDMCLK/SCCIO)~D37)
D38: J5.5, J5.5@2 (5), J22.5, J26.5, U2.D38 ((SDO3/RX1)D38)
D39: J5.1, J5.1@2 (1), J22.1, J26.1, U2.~D39 ((SCL4/SCK4/TX1)~D39)
D40: J5.2, J5.2@2 (2), J22.2, J26.2, U2.D40 ((SDA4/SDI4/RX1)D40)
D41: J5.10, J5.10@2 (10), J22.10, J26.10, U2.D41 ((BLEIF_IRQ/SWO/I2SWCLK)D41)
D42: J5.7, J5.7@2 (7), J22.7, J26.7, U2.~D42 ((SCL3/SCK3/TX1)~D42)
D43: J5.8, J5.8@2 (8), J22.8, J26.8, U2.~D43 ((SDA3/SDI3/RX1)~D43)
D44: J5.3, J5.3@2 (3), J22.3, J26.3, U2.~D44 ((SDO4)~D44)
D45: J5.9, J5.9@2 (9), J22.9, J26.9, U2.~D45 ((SWO/I2SDAT/PDMDATA)~D45)
GND: C1.2, C2.2, C3.2, C4.2, C5.2, C6.2, C7.2, C8.2, C9.2, C10.1, C11.1, C12.2, C13.2, C14.2, C15.2, C16.2, C17.2, C18.2, C19.2, D4.C, D5.C, D6.2, E1.2 (SEL), E1.3 (GND), E1.6 (GND), E1.7 (GND), E1.8 (GND), J1.GND, J1.GND2 (GND), J2.3 (GND), J2.5 (GND), J2.9 (GND), J3.3 (GND), J3.5 (GND), J3.9 (GNDDTCT), J4.1, J4.1@2 (1), J4.2, J4.2@2 (2), J6.1, J7.2 (GND), J7.15 (GND), J8.1, J8.2, J12.1, J12.2, J23.1, J23.2, J23.3, J23.4, J23.5, J23.6, J23.7, J23.8, J23.9, J23.10, J23.11, J23.12, J24.1, J24.2, J24.3, J24.4, J24.5, J24.6, J24.7, J24.8, J24.9, J24.10, J24.11, J24.12, R6.1, R7.1, R13.1, R20.2, S2.1, U1.2 (VSS1), U1.8 (VSSA), U1.16 (VSS2), U2.GND@1 (GND*6), U2.GND@22 (GND*6), U2.GND@38 (GND*6), U2.GND@39 (GND*6), U2.GND@47 (GND*6), U2.GND@59 (GND*6), U3.5 (RES), U3.6 (GND), U3.7 (GND), U3.8 (GND), U4.2 (GND), U5.2 (GND), X1.P2 (GND), X1.P4 (GND)
INTFC_NC5: J3.8 (NC/TDI), U1.11 (NC5)
INTFC_NC6: J3.6 (SWO/TDO), U1.12 (NC6)
INTFC_SWDCLK: J3.4 (SWDCLK/TCK), TP2.P$1, U1.10 (NC4)
INTFC_SWDIO: J3.2 (SWDIO/TMS), TP1.P$1, U1.13 (NC7)
LED_HID: D2.C, U1.30 (LED_HID)
LED_MSD: D1.C, U1.29 (LED_MSD)
LED_UART: D3.C, U1.31 (LED_UART)
unnamed: D1.A, R1.1
unnamed: D2.A, R2.1
unnamed: D3.A, R3.1
unnamed: J1.B5 (CC2), R6.2
unnamed: J1.A5 (CC1), R7.2
unnamed: D5.A, R5.1
unnamed: D4.A, R4.1
unnamed: D6.4, R16.1
unnamed: D6.6, R18.1
unnamed: R11.1, U1.14 (NRESET_FB_BL)
unnamed: TGT_SWD_CLK.1, U1.26 (TGT_SWCLK)
unnamed: C8.1, U1.17 (XTALIN), X1.P1 (1)
unnamed: C10.2, U2.XI, Y1.P$2 (2)
unnamed: C11.2, U2.XO, Y1.P$1 (1)
unnamed: C9.1, U1.18 (XTALOUT), X1.P3 (2)
unnamed: TGT_BOOT.1, U1.9 (NC1)
PDM_CLK: E1.4 (CLK), U2.~AD12 (~AD12(PDMCLK/TX1))
PDM_DATA: E1.1 (DATA), U2.~AD11 (~AD11(PDMDATA))
SCL: J6.4, J7.21 (SCL), U2.D8 ((SCL1/SCK1/TX1/SCCLK)D8), U3.1 (SCL/SPC)
SDA: J6.3, J7.22 (SDA), U2.D9 ((SDA1/SDI1/RX1/SCCIO)D9), U3.4 (SDA/SDI/SDO)
TGT_BOOT: R13.2, TGT_BOOT.2, U2.BOOT (~BOOT(SDO5/RX1/32KHZ))
TGT_RX: U1.25 (TGT_RX), U2.RXI-0 (~D49(RX0/SDA5/SDI5))
TGT_SWCLK: J2.4 (SWDCLK), TGT_SWD_CLK.2, U2.SWDCK (D20(SWDCK/TX1))
TGT_SWDIO: J2.2 (SWDIO), U1.27 (TGT_SWDIO), U2.SWDIO (D21(SWDIO/RX1/SCCRST))
TGT_SWO: J2.6 (SWO), U1.28 (TGT_SWO), U2.~D22 ((PDMCLK/SWO)~D22)
TGT_TX: U1.24 (TGT_TX), U2.TXO-0 (~D48(TX0/SCL5/SCK5))
USB_D+_P: R16.2, U1.3 (USB_D+)
USB_D+_R: D6.3, J1.A6 (D+), J1.B6 (D+)
USB_D-_P: R18.2, U1.4 (USB_D-)
USB_D-_R: D6.1, J1.A7 (D-), J1.B7 (D-)
V_USB: C12.1, C13.1, D6.5, J1.VBUS1 (VBUS), J1.VBUS2 (VBUS), J4.3, J4.3@2 (3), J4.4, J4.4@2 (4), J8.3, J8.4, J12.3, J12.4, R19.2, U1.6 (VREGIN), U5.1 (IN), U5.3 (EN)

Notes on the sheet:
I2C Address: 0x21
Camera
I2C Address: 0x19 (SA0 = 1)
Interface MCU - MKL26Z
Target - Artemis Module (Apollo3)
Connectors
USB
Sensors
Cut to isolate Artemis boot pin from interface chip
Cut to isolate Artemis swd clock from interface chip
power rail intended for output only

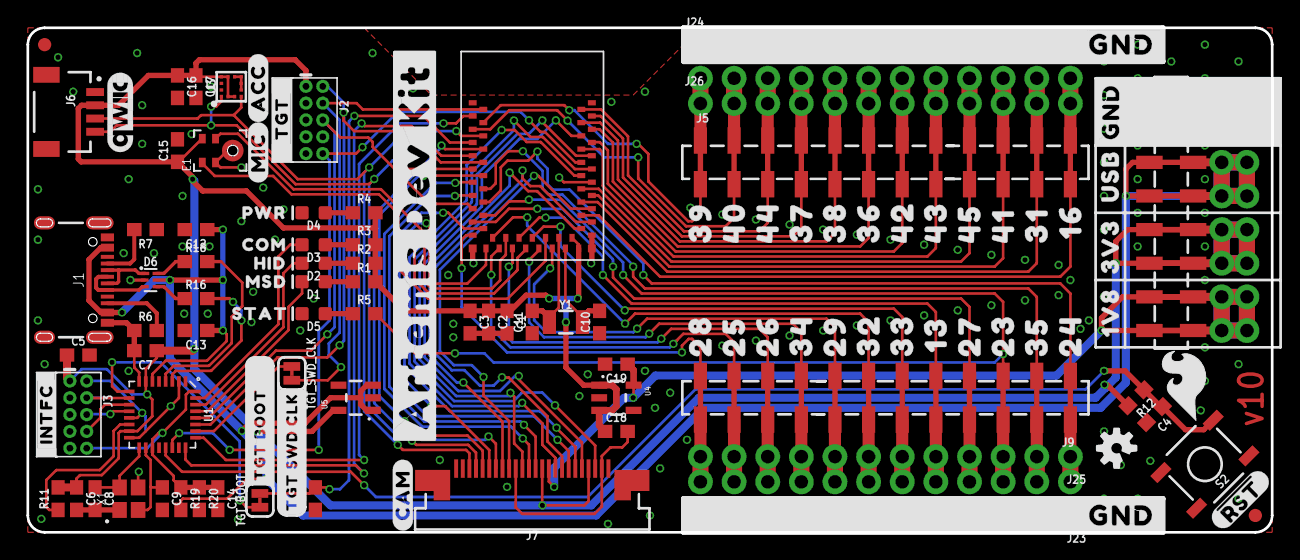
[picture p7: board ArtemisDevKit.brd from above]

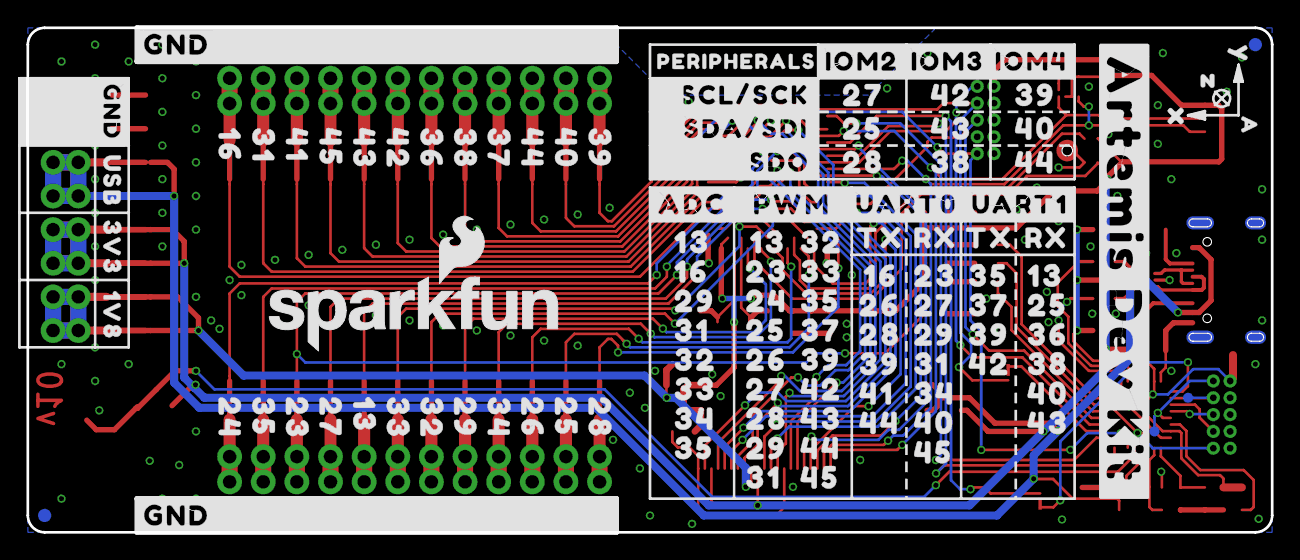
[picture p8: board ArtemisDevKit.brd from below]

Board: 2 copper layers, 94.0 x 38.1 mm, 229 parts (113 on the bottom side), 82 nets.

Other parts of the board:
U$1, U$2: #GND#10
U$3, U$132: 15_#GND#
U$4, U$129: 16_1V8
U$5, U$130: 17_3V3
U$6, U$131: 18_USB
U$7, U$64, U$98, U$147: 33_16
U$8, U$73, U$97, U$149, U$154: 41_31
U$9, U$68, U$96: 51_41
U$10, U$55, U$76, U$163: 55_45
U$11, U$54, U$86, U$91, U$161: 53_43
U$12, U$53, U$80, U$90, U$160: 52_42
U$13, U$52, U$83: 46_36
U$14, U$51, U$84, U$92: 48_38
U$15, U$50, U$78, U$158: 47_37
U$16, U$49, U$69, U$95, U$162: 54_44
U$17, U$48, U$75, U$85, U$94: 50_40
U$18, U$47, U$67, U$79, U$93, U$159: 49_39
U$19, U$58, U$110: 35_24
U$20, U$77, U$109, U$153, U$157: 45_35
U$21, U$57, U$70, U$108: 34_23
U$22, U$61, U$71, U$87, U$107: 38_27
U$23, U$56, U$81, U$106, U$146: 32_13
U$24, U$105, U$151, U$156: 43_33
U$25, U$104, U$150, U$155: 42_32
U$26, U$63, U$72, U$103, U$148: 40_29
U$27, U$74, U$102, U$152: 44_34
U$28, U$60, U$65, U$101: 37_26
U$29, U$59, U$82, U$88, U$100: 36_25
U$30, U$62, U$66, U$89, U$99: 39_28
U$31: 19_#IOM2#
U$32: QWIIC_6MM
U$33: 20_#IOM3#
U$34: 21_#IOM4#
U$35: #TGT#3
U$36: #ARTEMIS_DEV_KIT#0
U$37: #SCL#SCK#23
U$38: 30_#PWM#
U$39: 29_#ADC#
U$40: 25_#UART0#
U$41: 26_#UART1#
U$42, U$43: 27_TX
U$44, U$46: 28_RX
U$45: SFE_LOGO_FLAME_.2
U$111: #SDA#SDI#24
U$112: #SDO#25
U$113: 14_A
U$114: 15_X
U$115: 16_Y
U$116: 17_Z
U$117: 7_COM
U$118: 8_HID
U$119: 9_MSD
U$120: 10_STAT
U$121: 6_PWR
U$122: #ARTEMIS_DEV_KIT#1
U$123: #INTFC#2
U$124: #TGT_BOOT#4
U$125: #TGT_SWD_CLK#5
U$126: #CAM#13
U$137: #MIC#11
U$138: #ACC#12
U$140, U$141: 14_#GND#
U$142: ##RST##18
U$145: 19_PERIPHERALS

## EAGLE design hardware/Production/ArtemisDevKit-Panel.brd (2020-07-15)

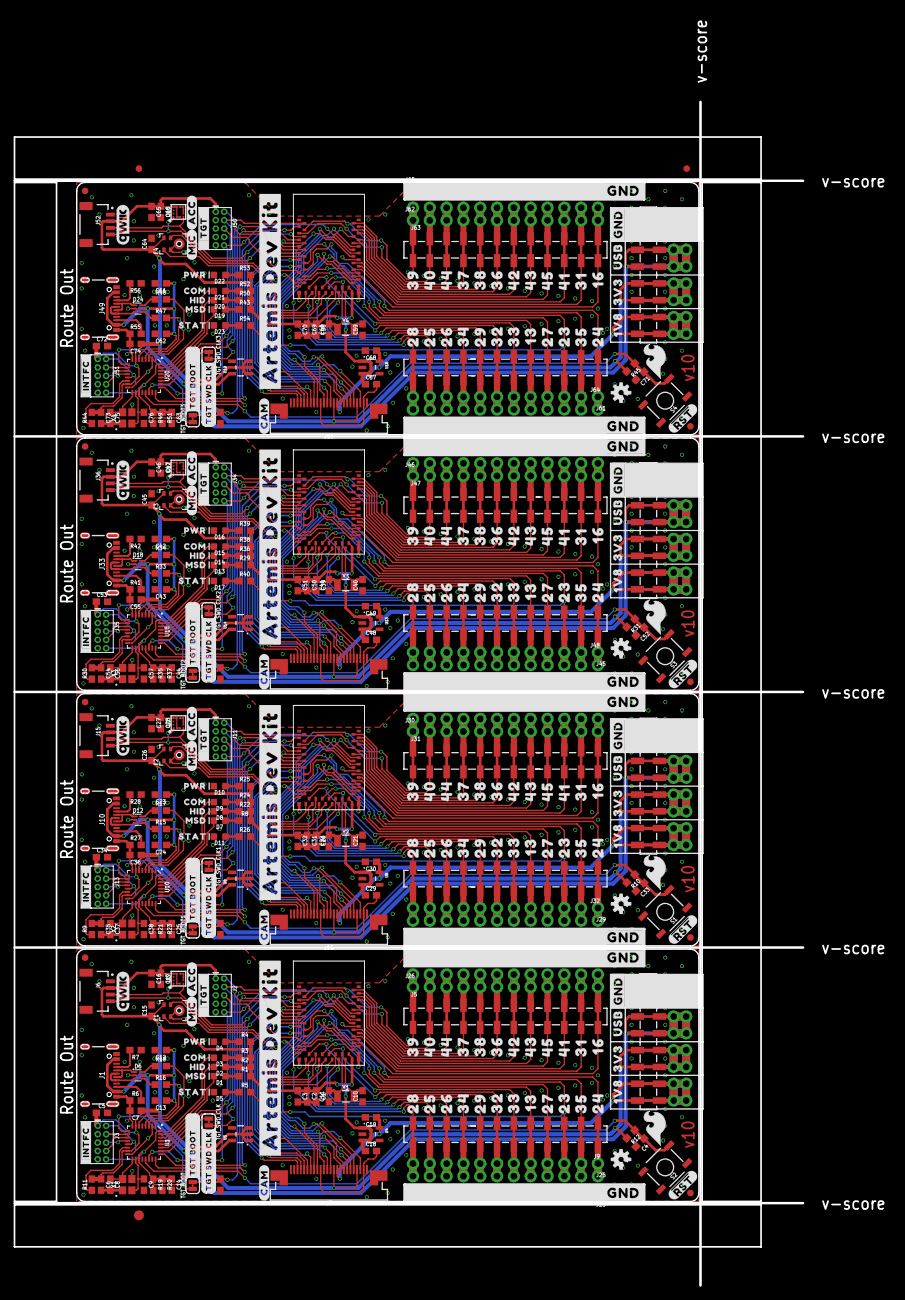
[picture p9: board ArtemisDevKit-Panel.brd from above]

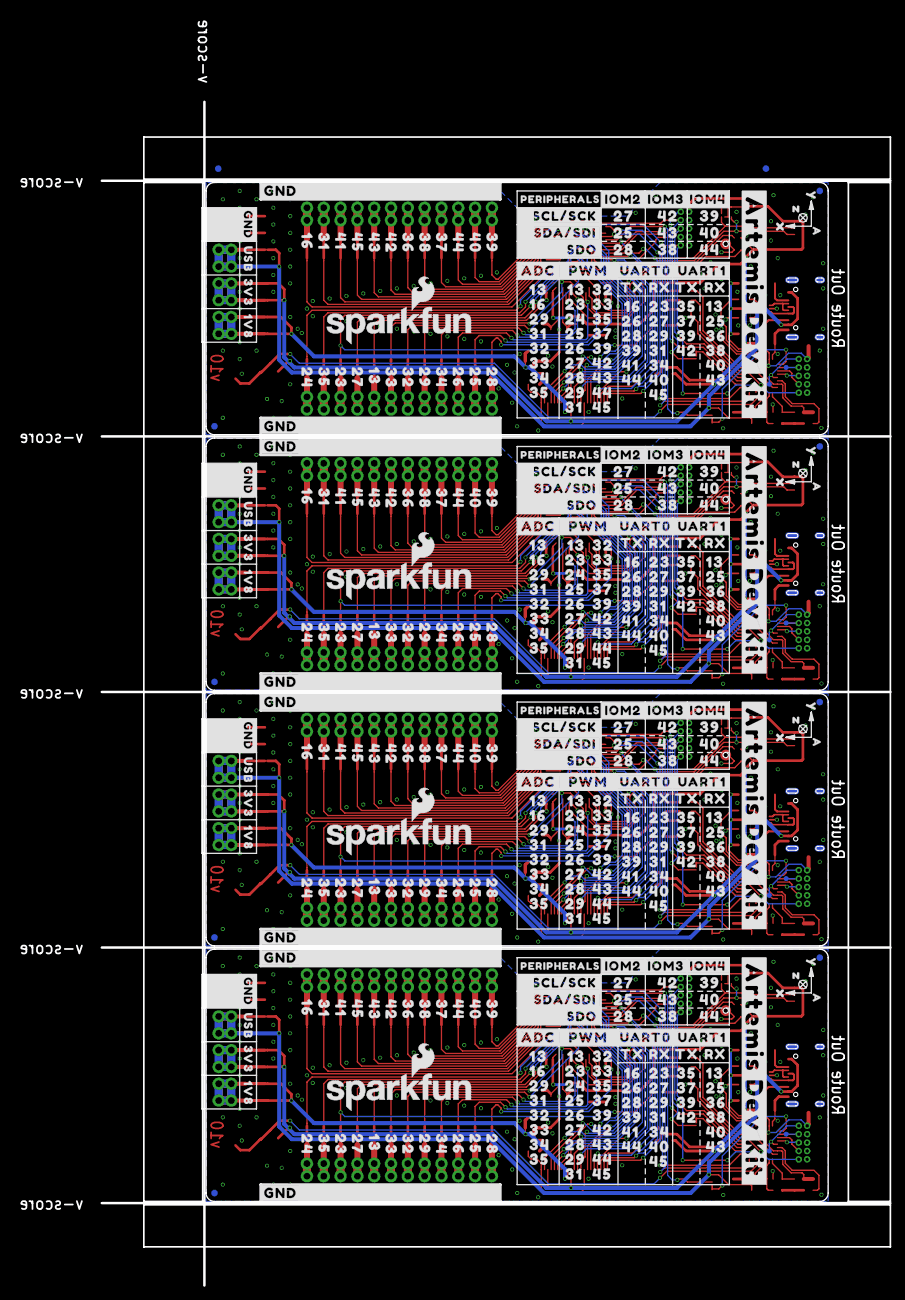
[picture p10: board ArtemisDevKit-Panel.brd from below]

Board: 2 copper layers, 119.1 x 178.8 mm, 917 parts (454 on the bottom side), 328 nets.

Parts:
C1, C17, C20, C28, C39, C47, C58, C66: 10uF; 0603
C2, C12, C15, C18, C19, C23, C26, C29, C30, C31, C42, C45, C48, C49, C50, C61, C64, C67, C68, C69: 1.0uF; 0603
C3, C4, C6, C7, C13, C14, C16, C24, C25, C27, C32, C33, C35, C36, C43, C44, C46, C51, C52, C54, C55, C62, C63, C65, C70, C71, C73, C74: 0.1uF; 0603
C5, C34, C53, C72: 2.2uF; 0603
C8, C9, C37, C38, C56, C57, C75, C76: 12pF; 0603
C10, C11, C21, C22, C40, C41, C59, C60: 15pF; 0603
D1, D5, D7, D11, D13, D17, D19, D23: BLUE; LED-0603
D2, D8, D14, D20: GREEN; LED-0603
D3, D9, D15, D21: Yellow; LED-0603
D4, D10, D16, D22: RED; LED-0603
D6, D12, D18, D24: PRTR5V0U2F; SOT886
E1, E2, E3, E4: SPH0641LM4H-1; SPH0641LM4H-1_MICROPHONE
E$1, E$2, E$3, E$4: FIDUCIAL-1X2
E$5: FIDUCIAL-1.5X3
FD1, FD2, FD3, FD4, FD5, FD6, FD7, FD8, FD9, FD10, FD11, FD12, FD13, FD14, FD15, FD16: FIDUCIAL1X2; FIDUCIAL-1X2
J1, J10, J33, J49: USB; USB-C-16P
J2, J11, J34, J50: CORTEX_JTAG_DEBUG_MINIMUM_PTH; 2X5-PTH-1.27MM
J3, J13, J35, J51: CORTEX_JTAG_DEBUG_PTH; 2X5-PTH-1.27MM
J4, J17, J38, J54: SMD; 1X08_SMD_COMBINED
J5, J9, J31, J32, J47, J48, J63, J64: 1X12_SMD_COMBINED
J6, J15, J36, J52: QWIIC_RIGHT_ANGLE; JST04_1MM_RA
J7, J16, J37, J53: CAMERA-HIMAXBOTTOM-CONTACT; FPC-24-AMPHENOL-SFV24R-1STE1HLF
J8, J12, J18, J19, J39, J40, J55, J56: PTH; 1X08_NO_SILK
J14, J20, J21, J22, J23, J24, J25, J26, J27, J28, J29, J30, J41, J42, J43, J44, J45, J46, J57, J58, J59, J60, J61, J62: PTH; 1X12_NO_SILK
LOGO1, LOGO3, LOGO5, LOGO7: OSHW-LOGOS; OSHW-LOGO-S
LOGO2, LOGO4, LOGO6, LOGO8: SFE_LOGO_NAME_FLAME.2_INCH; SFE_LOGO_NAME_FLAME_.2
R1, R2, R3, R4, R5, R8, R22, R24, R25, R26, R29, R36, R38, R39, R40, R43, R50, R52, R53, R54: 330; 0603
R6, R7, R27, R28, R41, R42, R55, R56: 5.1k; 0603
R9, R10, R11, R12, R13, R14, R20, R23, R30, R31, R32, R37, R44, R45, R46, R51: 10k; 0603
R15, R16, R17, R18, R33, R34, R47, R48: 33; 0603
R19, R21, R35, R49: 5.62k; 0603
S1, S2, S3, S4: TGT_RST; TACTILE_SWITCH_SMD_5.2MM
TGT_BOOT, TGT_BOOT1, TGT_BOOT2, TGT_BOOT3: JUMPER-SMT_2_NC_TRACE_SILK; SMT-JUMPER_2_NC_TRACE_SILK
TGT_SWD_CLK, TGT_SWD_CLK1, TGT_SWD_CLK2, TGT_SWD_CLK3: JUMPER-SMT_2_NC_TRACE_SILK; SMT-JUMPER_2_NC_TRACE_SILK
TP1, TP3, TP5, TP7: INTFC_SWDIO; PAD.03X.03
TP2, TP4, TP6, TP8: INTFC_SWDCLK; PAD.03X.03
U1, U10, U15, U20: DAPLINK_KL26Z128VFM4; QFN-32-NOPAD
U2, U6, U11, U16: ARTEMIS_MODULESMD; ARTEMIS_FP
U3, U7, U12, U17: LIS2DH12; LGA-12-LISDH12
U4, U8, U13, U18: AP2127K-1.8V; SOT23-5
U5, U9, U14, U19: 3.3V; SOT23-5
U$1, U$2, U$133, U$134, U$311, U$312, U$465, U$466: #GND#10
U$3, U$132, U$135, U$177, U$313, U$331, U$467, U$485: 15_#GND#
U$4, U$129, U$136, U$174, U$314, U$328, U$468, U$482: 16_1V8
U$5, U$130, U$139, U$175, U$315, U$329, U$469, U$483: 17_3V3
U$6, U$131, U$143, U$176, U$316, U$330, U$470, U$484: 18_USB
U$7, U$64, U$98, U$147, U$184, U$209, U$234, U$277, U$338, U$363, U$388, U$431, U$492, U$517, U$542, U$585: 33_16
U$8, U$73, U$97, U$149, U$154, U$185, U$211, U$224, U$243, U$276, U$339, U$365, U$378, U$397, U$430, U$493, U$519, U$532, U$551, U$584: 41_31
U$9, U$68, U$96, U$186, U$238, U$275, U$340, U$392, U$429, U$494, U$546, U$583: 51_41
U$10, U$55, U$76, U$163, U$187, U$233, U$246, U$274, U$341, U$387, U$400, U$428, U$495, U$541, U$554, U$582: 55_45
U$11, U$54, U$86, U$91, U$161, U$188, U$231, U$256, U$261, U$273, U$342, U$385, U$410, U$415, U$427, U$496, U$539, U$564, U$569, U$581: 53_43
U$12, U$53, U$80, U$90, U$160, U$189, U$230, U$250, U$260, U$272, U$343, U$384, U$404, U$414, U$426, U$497, U$538, U$558, U$568, U$580: 52_42
U$13, U$52, U$83, U$190, U$253, U$271, U$344, U$407, U$425, U$498, U$561, U$579: 46_36
U$14, U$51, U$84, U$92, U$191, U$254, U$262, U$270, U$345, U$408, U$416, U$424, U$499, U$562, U$570, U$578: 48_38
U$15, U$50, U$78, U$158, U$192, U$228, U$248, U$269, U$346, U$382, U$402, U$423, U$500, U$536, U$556, U$577: 47_37
U$16, U$49, U$69, U$95, U$162, U$193, U$232, U$239, U$265, U$268, U$347, U$386, U$393, U$419, U$422, U$501, U$540, U$547, U$573, U$576: 54_44
U$17, U$48, U$75, U$85, U$94, U$194, U$245, U$255, U$264, U$267, U$348, U$399, U$409, U$418, U$421, U$502, U$553, U$563, U$572, U$575: 50_40
U$18, U$47, U$67, U$79, U$93, U$159, U$195, U$229, U$237, U$249, U$263, U$266, U$349, U$383, U$391, U$403, U$417, U$420, U$503, U$537, U$545, U$557, U$571, U$574: 49_39
U$19, U$58, U$110, U$196, U$218, U$289, U$350, U$372, U$443, U$504, U$526, U$597: 35_24
U$20, U$77, U$109, U$153, U$157, U$197, U$215, U$227, U$247, U$288, U$351, U$369, U$381, U$401, U$442, U$505, U$523, U$535, U$555, U$596: 45_35
U$21, U$57, U$70, U$108, U$198, U$217, U$240, U$287, U$352, U$371, U$394, U$441, U$506, U$525, U$548, U$595: 34_23
U$22, U$61, U$71, U$87, U$107, U$199, U$221, U$241, U$257, U$286, U$353, U$375, U$395, U$411, U$440, U$507, U$529, U$549, U$565, U$594: 38_27
U$23, U$56, U$81, U$106, U$146, U$200, U$208, U$216, U$251, U$285, U$354, U$362, U$370, U$405, U$439, U$508, U$516, U$524, U$559, U$593: 32_13
U$24, U$105, U$151, U$156, U$201, U$213, U$226, U$284, U$355, U$367, U$380, U$438, U$509, U$521, U$534, U$592: 43_33
U$25, U$104, U$150, U$155, U$202, U$212, U$225, U$283, U$356, U$366, U$379, U$437, U$510, U$520, U$533, U$591: 42_32
U$26, U$63, U$72, U$103, U$148, U$203, U$210, U$223, U$242, U$282, U$357, U$364, U$377, U$396, U$436, U$511, U$518, U$531, U$550, U$590: 40_29
U$27, U$74, U$102, U$152, U$204, U$214, U$244, U$281, U$358, U$368, U$398, U$435, U$512, U$522, U$552, U$589: 44_34
U$28, U$60, U$65, U$101, U$205, U$220, U$235, U$280, U$359, U$374, U$389, U$434, U$513, U$528, U$543, U$588: 37_26
U$29, U$59, U$82, U$88, U$100, U$206, U$219, U$252, U$258, U$279, U$360, U$373, U$406, U$412, U$433, U$514, U$527, U$560, U$566, U$587: 36_25
U$30, U$62, U$66, U$89, U$99, U$207, U$222, U$236, U$259, U$278, U$361, U$376, U$390, U$413, U$432, U$515, U$530, U$544, U$567, U$586: 39_28
U$31, U$167, U$321, U$475: 19_#IOM2#
U$32, U$127, U$309, U$463: QWIIC_6MM
U$33, U$168, U$322, U$476: 20_#IOM3#
U$34, U$169, U$323, U$477: 21_#IOM4#
U$35, U$304, U$458, U$612: #TGT#3
U$36, U$303, U$457, U$611: #ARTEMIS_DEV_KIT#0
U$37, U$299, U$453, U$607: #SCL#SCK#23
U$38, U$170, U$324, U$478: 30_#PWM#
U$39, U$171, U$325, U$479: 29_#ADC#
U$40, U$172, U$326, U$480: 25_#UART0#
U$41, U$173, U$327, U$481: 26_#UART1#
U$42, U$43, U$144, U$164, U$317, U$318, U$471, U$472: 27_TX
U$44, U$46, U$165, U$166, U$319, U$320, U$473, U$474: 28_RX
U$45, U$128, U$310, U$464: SFE_LOGO_FLAME_.2
U$111, U$300, U$454, U$608: #SDA#SDI#24
U$112, U$301, U$455, U$609: #SDO#25
U$113, U$290, U$444, U$598: 14_A
U$114, U$291, U$445, U$599: 15_X
U$115, U$292, U$446, U$600: 16_Y
U$116, U$293, U$447, U$601: 17_Z
U$117, U$294, U$448, U$602: 7_COM
U$118, U$295, U$449, U$603: 8_HID
U$119, U$296, U$450, U$604: 9_MSD
U$120, U$297, U$451, U$605: 10_STAT
U$121, U$298, U$452, U$606: 6_PWR
U$122, U$302, U$456, U$610: #ARTEMIS_DEV_KIT#1
U$123, U$305, U$459, U$613: #INTFC#2
U$124, U$306, U$460, U$614: #TGT_BOOT#4
U$125, U$307, U$461, U$615: #TGT_SWD_CLK#5
U$126, U$308, U$462, U$616: #CAM#13
U$137, U$178, U$332, U$486: #MIC#11
U$138, U$179, U$333, U$487: #ACC#12
U$140, U$141, U$180, U$181, U$334, U$335, U$488, U$489: 14_#GND#
U$142, U$182, U$336, U$490: ##RST##18
U$145, U$183, U$337, U$491: 19_PERIPHERALS
X1, X2, X3, X4: 16MHz; CRYSTAL-SMD-2X2.5MM
Y1, Y2, Y3, Y4: 32.768kHz; CRYSTAL-SMD-3.2X1.5MM

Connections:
1.8V: C19.1, J4.7, J4.7@2, J4.8, J4.8@2, J7.10, J8.7, J8.8, J12.7, J12.8, U4.5
1.8V1: C30.1, J16.10, J17.7, J17.7@2, J17.8, J17.8@2, J18.7, J18.8, J19.7, J19.8, U8.5
1.8V2: C49.1, J37.10, J38.7, J38.7@2, J38.8, J38.8@2, J39.7, J39.8, J40.7, J40.8, U13.5
1.8V3: C68.1, J53.10, J54.7, J54.7@2, J54.8, J54.8@2, J55.7, J55.8, J56.7, J56.8, U18.5
3.3V: C1.1, C2.1, C3.1, C5.1, C6.1, C7.1, C15.1, C16.1, C17.1, C18.1, E1.5, J2.1, J3.1, J4.5, J4.5@2, J4.6, J4.6@2, J6.2, J7.4, J7.11, J8.5, J8.6, J12.5, J12.6, R1.2, R2.2, R3.2, R4.2, R11.2, R12.2, U1.7, U1.15, U2.VDD@36, U2.VDD@37, U3.2, U3.3, U3.9, U3.10, U4.1, U4.3, U5.5
3.3V1: C20.1, C26.1, C27.1, C28.1, C29.1, C31.1, C32.1, C34.1, C35.1, C36.1, E2.5, J11.1, J13.1, J15.2, J16.4, J16.11, J17.5, J17.5@2, J17.6, J17.6@2, J18.5, J18.6, J19.5, J19.6, R8.2, R9.2, R10.2, R22.2, R24.2, R25.2, U6.VDD@36, U6.VDD@37, U7.2, U7.3, U7.9, U7.10, U8.1, U8.3, U9.5, U10.7, U10.15
3.3V2: C39.1, C45.1, C46.1, C47.1, C48.1, C50.1, C51.1, C53.1, C54.1, C55.1, E3.5, J34.1, J35.1, J36.2, J37.4, J37.11, J38.5, J38.5@2, J38.6, J38.6@2, J39.5, J39.6, J40.5, J40.6, R29.2, R30.2, R31.2, R36.2, R38.2, R39.2, U11.VDD@36, U11.VDD@37, U12.2, U12.3, U12.9, U12.10, U13.1, U13.3, U14.5, U15.7, U15.15
3.3V3: C58.1, C64.1, C65.1, C66.1, C67.1, C69.1, C70.1, C72.1, C73.1, C74.1, E4.5, J50.1, J51.1, J52.2, J53.4, J53.11, J54.5, J54.5@2, J54.6, J54.6@2, J55.5, J55.6, J56.5, J56.6, R43.2, R44.2, R45.2, R50.2, R52.2, R53.2, U16.VDD@36, U16.VDD@37, U17.2, U17.3, U17.9, U17.10, U18.1, U18.3, U19.5, U20.7, U20.15
!INTFC_RST: C14.1, J3.10, R19.1, R20.1, U1.19, U1.32
!INTFC_RST1: C25.1, J13.10, R21.1, R23.1, U10.19, U10.32
!INTFC_RST2: C44.1, J35.10, R35.1, R37.1, U15.19, U15.32
!INTFC_RST3: C63.1, J51.10, R49.1, R51.1, U20.19, U20.32
!RST!_BTN: C4.1, R12.1, S2.3, U1.21
!RST!_BTN1: C33.1, R10.1, S1.3, U10.21
!RST!_BTN2: C52.1, R31.1, S3.3, U15.21
!RST!_BTN3: C71.1, R45.1, S4.3, U20.21
!TGT_RST: J2.10, U1.22, U2.~RST
!TGT_RST1: J11.10, U6.~RST, U10.22
!TGT_RST2: J34.10, U11.~RST, U15.22
!TGT_RST3: J50.10, U16.~RST, U20.22
CAMERA_D0: J7.14, U2.D0
CAMERA_D1: J7.3, U2.D1
CAMERA_D2: J7.9, U2.D2
CAMERA_D3: J7.5, U2.D3
CAMERA_D4: J7.12, U2.~D4
CAMERA_D5: J7.20, U2.~D5
CAMERA_D6: J7.19, U2.~D6
CAMERA_D7: J7.13, U2.D7
CAMERA_D8: J16.3, U6.D1
CAMERA_D9: J16.5, U6.D3
CAMERA_D10: J16.12, U6.~D4
CAMERA_D11: J16.20, U6.~D5
CAMERA_D12: J16.19, U6.~D6
CAMERA_D13: J16.13, U6.D7
CAMERA_D14: J16.14, U6.D0
CAMERA_D15: J16.9, U6.D2
CAMERA_D16: J37.3, U11.D1
CAMERA_D17: J37.5, U11.D3
CAMERA_D18: J37.12, U11.~D4
CAMERA_D19: J37.20, U11.~D5
CAMERA_D20: J37.19, U11.~D6
CAMERA_D21: J37.13, U11.D7
CAMERA_D22: J37.14, U11.D0
CAMERA_D23: J37.9, U11.D2
CAMERA_D24: J53.3, U16.D1
CAMERA_D25: J53.5, U16.D3
CAMERA_D26: J53.12, U16.~D4
CAMERA_D27: J53.20, U16.~D5
CAMERA_D28: J53.19, U16.~D6
CAMERA_D29: J53.13, U16.D7
CAMERA_D30: J53.14, U16.D0
CAMERA_D31: J53.9, U16.D2
CAMERA_HSYNC: J7.16, U2.D17
CAMERA_HSYNC1: J16.16, U6.D17
CAMERA_HSYNC2: J37.16, U11.D17
CAMERA_HSYNC3: J53.16, U16.D17
CAMERA_INT: J7.18, U2.D10
CAMERA_INT1: J16.18, U6.D10
CAMERA_INT2: J37.18, U11.D10
CAMERA_INT3: J53.18, U16.D10
CAMERA_MCLK: J7.8, U2.~D18
CAMERA_MCLK1: J16.8, U6.~D18
CAMERA_MCLK2: J37.8, U11.~D18
CAMERA_MCLK3: J53.8, U16.~D18
CAMERA_PCLK: J7.17, U2.~D19
CAMERA_PCLK1: J16.17, U6.~D19
CAMERA_PCLK2: J37.17, U11.~D19
CAMERA_PCLK3: J53.17, U16.~D19
CAMERA_TRIG: J7.7, U2.D14
CAMERA_TRIG1: J16.7, U6.D14
CAMERA_TRIG2: J37.7, U11.D14
CAMERA_TRIG3: J53.7, U16.D14
CAMERA_VSYNC: J7.6, U2.D15
CAMERA_VSYNC1: J16.6, U6.D15
CAMERA_VSYNC2: J37.6, U11.D15
CAMERA_VSYNC3: J53.6, U16.D15
D1: J21.3, J30.3, J31.3, J31.3@2, U6.~D44
D2: J21.2, J30.2, J31.2, J31.2@2, U6.D40
D3: J21.1, J30.1, J31.1, J31.1@2, U6.~D39
D4: J21.5, J30.5, J31.5, J31.5@2, U6.D38
D5: J21.8, J30.8, J31.8, J31.8@2, U6.~D43
D6: J21.7, J30.7, J31.7, J31.7@2, U6.~D42
D7: J21.10, J30.10, J31.10, J31.10@2, U6.D41
D8: J20.11, J29.11, J32.11, J32.11@2, U6.~D25
D9: J20.10, J29.10, J32.10, J32.10@2, U6.~D26
D10: J20.4, J29.4, J32.4, J32.4@2, U6.~D27
D11: J20.12, J29.12, J32.12, J32.12@2, U6.~D28
D12: J21.6, J30.6, J31.6, J31.6@2, U6.D36
D13: J9.5, J9.5@2, J14.5, J25.5, U2.~AD13
D14: J21.4, J30.4, J31.4, J31.4@2, U6.~D37
D15: J21.9, J30.9, J31.9, J31.9@2, U6.~D45
D16: J5.12, J5.12@2, J22.12, J26.12, U2.AD16
D17: J20.5, J29.5, J32.5, J32.5@2, U6.~AD13
D18: J21.12, J30.12, J31.12, J31.12@2, U6.AD16
D19: J20.8, J29.8, J32.8, J32.8@2, U6.~AD29
D20: J21.11, J30.11, J31.11, J31.11@2, U6.~AD31
D21: J20.7, J29.7, J32.7, J32.7@2, U6.~AD32
D22: J20.6, J29.6, J32.6, J32.6@2, U6.~AD33/SWO
D23: J20.9, J29.9, J32.9, J32.9@2, U6.AD34
D23_LED: J9.3, J9.3@2, J14.3, J25.3, R5.2, U2.~D23
D23_LED1: J20.3, J29.3, J32.3, J32.3@2, R26.2, U6.~D23
D23_LED2: J41.3, J45.3, J48.3, J48.3@2, R40.2, U11.~D23
D23_LED3: J57.3, J61.3, J64.3, J64.3@2, R54.2, U16.~D23
D24: J9.1, J9.1@2, J14.1, J25.1, U2.~D24
D25: J9.11, J9.11@2, J14.11, J25.11, U2.~D25
D26: J9.10, J9.10@2, J14.10, J25.10, U2.~D26
D27: J9.4, J9.4@2, J14.4, J25.4, U2.~D27
D28: J9.12, J9.12@2, J14.12, J25.12, U2.~D28
D29: J9.8, J9.8@2, J14.8, J25.8, U2.~AD29
D30: J20.1, J29.1, J32.1, J32.1@2, U6.~D24
D31: J5.11, J5.11@2, J22.11, J26.11, U2.~AD31
D32: J9.7, J9.7@2, J14.7, J25.7, U2.~AD32
D33: J9.6, J9.6@2, J14.6, J25.6, U2.~AD33/SWO
D34: J9.9, J9.9@2, J14.9, J25.9, U2.AD34
D35: J9.2, J9.2@2, J14.2, J25.2, U2.~AD35
D36: J5.6, J5.6@2, J22.6, J26.6, U2.D36
D37: J5.4, J5.4@2, J22.4, J26.4, U2.~D37
D38: J5.5, J5.5@2, J22.5, J26.5, U2.D38
D39: J5.1, J5.1@2, J22.1, J26.1, U2.~D39
D40: J5.2, J5.2@2, J22.2, J26.2, U2.D40
D41: J5.10, J5.10@2, J22.10, J26.10, U2.D41
D42: J5.7, J5.7@2, J22.7, J26.7, U2.~D42
D43: J5.8, J5.8@2, J22.8, J26.8, U2.~D43
D44: J5.3, J5.3@2, J22.3, J26.3, U2.~D44
D45: J5.9, J5.9@2, J22.9, J26.9, U2.~D45
D46: J20.2, J29.2, J32.2, J32.2@2, U6.~AD35
D47: J42.3, J46.3, J47.3, J47.3@2, U11.~D44
D48: J42.2, J46.2, J47.2, J47.2@2, U11.D40
D49: J42.1, J46.1, J47.1, J47.1@2, U11.~D39
D50: J42.5, J46.5, J47.5, J47.5@2, U11.D38
D51: J42.8, J46.8, J47.8, J47.8@2, U11.~D43
D52: J42.7, J46.7, J47.7, J47.7@2, U11.~D42
D53: J42.10, J46.10, J47.10, J47.10@2, U11.D41
D54: J41.11, J45.11, J48.11, J48.11@2, U11.~D25
D55: J41.10, J45.10, J48.10, J48.10@2, U11.~D26
D56: J41.4, J45.4, J48.4, J48.4@2, U11.~D27
D57: J41.12, J45.12, J48.12, J48.12@2, U11.~D28
D58: J42.6, J46.6, J47.6, J47.6@2, U11.D36
D59: J42.4, J46.4, J47.4, J47.4@2, U11.~D37
D60: J42.9, J46.9, J47.9, J47.9@2, U11.~D45
D61: J41.5, J45.5, J48.5, J48.5@2, U11.~AD13
D62: J42.12, J46.12, J47.12, J47.12@2, U11.AD16
D63: J41.8, J45.8, J48.8, J48.8@2, U11.~AD29
D64: J42.11, J46.11, J47.11, J47.11@2, U11.~AD31
D65: J41.7, J45.7, J48.7, J48.7@2, U11.~AD32
D66: J41.6, J45.6, J48.6, J48.6@2, U11.~AD33/SWO
D67: J41.9, J45.9, J48.9, J48.9@2, U11.AD34
D68: J41.1, J45.1, J48.1, J48.1@2, U11.~D24
D69: J41.2, J45.2, J48.2, J48.2@2, U11.~AD35
D70: J58.3, J62.3, J63.3, J63.3@2, U16.~D44
D71: J58.2, J62.2, J63.2, J63.2@2, U16.D40
D72: J58.1, J62.1, J63.1, J63.1@2, U16.~D39
D73: J58.5, J62.5, J63.5, J63.5@2, U16.D38
D74: J58.8, J62.8, J63.8, J63.8@2, U16.~D43
D75: J58.7, J62.7, J63.7, J63.7@2, U16.~D42
D76: J58.10, J62.10, J63.10, J63.10@2, U16.D41
D77: J57.11, J61.11, J64.11, J64.11@2, U16.~D25
D78: J57.10, J61.10, J64.10, J64.10@2, U16.~D26
D79: J57.4, J61.4, J64.4, J64.4@2, U16.~D27
D80: J57.12, J61.12, J64.12, J64.12@2, U16.~D28
D81: J58.6, J62.6, J63.6, J63.6@2, U16.D36
D82: J58.4, J62.4, J63.4, J63.4@2, U16.~D37
D83: J58.9, J62.9, J63.9, J63.9@2, U16.~D45
D84: J57.5, J61.5, J64.5, J64.5@2, U16.~AD13
D85: J58.12, J62.12, J63.12, J63.12@2, U16.AD16
D86: J57.8, J61.8, J64.8, J64.8@2, U16.~AD29
D87: J58.11, J62.11, J63.11, J63.11@2, U16.~AD31
D88: J57.7, J61.7, J64.7, J64.7@2, U16.~AD32
D89: J57.6, J61.6, J64.6, J64.6@2, U16.~AD33/SWO
D90: J57.9, J61.9, J64.9, J64.9@2, U16.AD34
D91: J57.1, J61.1, J64.1, J64.1@2, U16.~D24
D92: J57.2, J61.2, J64.2, J64.2@2, U16.~AD35
GND: C1.2, C2.2, C3.2, C4.2, C5.2, C6.2, C7.2, C8.2, C9.2, C10.1, C11.1, C12.2, C13.2, C14.2, C15.2, C16.2, C17.2, C18.2, C19.2, D4.C, D5.C, D6.2, E1.2, E1.3, E1.6, E1.7, E1.8, J1.GND, J1.GND2, J2.3, J2.5, J2.9, J3.3, J3.5, J3.9, J4.1, J4.1@2, J4.2, J4.2@2, J6.1, J7.2, J7.15, J8.1, J8.2, J12.1, J12.2, J23.1, J23.2, J23.3, J23.4, J23.5, J23.6, J23.7, J23.8, J23.9, J23.10, J23.11, J23.12, J24.1, J24.2, J24.3, J24.4, J24.5, J24.6, J24.7, J24.8, J24.9, J24.10, J24.11, J24.12, R6.1, R7.1, R13.1, R20.2, S2.1, U1.2, U1.8, U1.16, U2.GND@1, U2.GND@22, U2.GND@38, U2.GND@39, U2.GND@47, U2.GND@59, U3.5, U3.6, U3.7, U3.8, U4.2, U5.2, X1.P2, X1.P4
GND1: C20.2, C21.1, C22.1, C23.2, C24.2, C25.2, C26.2, C27.2, C28.2, C29.2, C30.2, C31.2, C32.2, C33.2, C34.2, C35.2, C36.2, C37.2, C38.2, D10.C, D11.C, D12.2, E2.2, E2.3, E2.6, E2.7, E2.8, J10.GND, J10.GND2, J11.3, J11.5, J11.9, J13.3, J13.5, J13.9, J15.1, J16.2, J16.15, J17.1, J17.1@2, J17.2, J17.2@2, J18.1, J18.2, J19.1, J19.2, J27.1, J27.2, J27.3, J27.4, J27.5, J27.6, J27.7, J27.8, J27.9, J27.10, J27.11, J27.12, J28.1, J28.2, J28.3, J28.4, J28.5, J28.6, J28.7, J28.8, J28.9, J28.10, J28.11, J28.12, R14.1, R23.2, R27.1, R28.1, S1.1, U6.GND@1, U6.GND@22, U6.GND@38, U6.GND@39, U6.GND@47, U6.GND@59, U7.5, U7.6, U7.7, U7.8, U8.2, U9.2, U10.2, U10.8, U10.16, X2.P2, X2.P4
GND2: C39.2, C40.1, C41.1, C42.2, C43.2, C44.2, C45.2, C46.2, C47.2, C48.2, C49.2, C50.2, C51.2, C52.2, C53.2, C54.2, C55.2, C56.2, C57.2, D16.C, D17.C, D18.2, E3.2, E3.3, E3.6, E3.7, E3.8, J33.GND, J33.GND2, J34.3, J34.5, J34.9, J35.3, J35.5, J35.9, J36.1, J37.2, J37.15, J38.1, J38.1@2, J38.2, J38.2@2, J39.1, J39.2, J40.1, J40.2, J43.1, J43.2, J43.3, J43.4, J43.5, J43.6, J43.7, J43.8, J43.9, J43.10, J43.11, J43.12, J44.1, J44.2, J44.3, J44.4, J44.5, J44.6, J44.7, J44.8, J44.9, J44.10, J44.11, J44.12, R32.1, R37.2, R41.1, R42.1, S3.1, U11.GND@1, U11.GND@22, U11.GND@38, U11.GND@39, U11.GND@47, U11.GND@59, U12.5, U12.6, U12.7, U12.8, U13.2, U14.2, U15.2, U15.8, U15.16, X3.P2, X3.P4
GND3: C58.2, C59.1, C60.1, C61.2, C62.2, C63.2, C64.2, C65.2, C66.2, C67.2, C68.2, C69.2, C70.2, C71.2, C72.2, C73.2, C74.2, C75.2, C76.2, D22.C, D23.C, D24.2, E4.2, E4.3, E4.6, E4.7, E4.8, J49.GND, J49.GND2, J50.3, J50.5, J50.9, J51.3, J51.5, J51.9, J52.1, J53.2, J53.15, J54.1, J54.1@2, J54.2, J54.2@2, J55.1, J55.2, J56.1, J56.2, J59.1, J59.2, J59.3, J59.4, J59.5, J59.6, J59.7, J59.8, J59.9, J59.10, J59.11, J59.12, J60.1, J60.2, J60.3, J60.4, J60.5, J60.6, J60.7, J60.8, J60.9, J60.10, J60.11, J60.12, R46.1, R51.2, R55.1, R56.1, S4.1, U16.GND@1, U16.GND@22, U16.GND@38, U16.GND@39, U16.GND@47, U16.GND@59, U17.5, U17.6, U17.7, U17.8, U18.2, U19.2, U20.2, U20.8, U20.16, X4.P2, X4.P4
INTFC_NC1: J13.6, U10.12
INTFC_NC2: J13.8, U10.11
INTFC_NC3: J35.6, U15.12
INTFC_NC4: J35.8, U15.11
INTFC_NC5: J3.8, U1.11
INTFC_NC6: J3.6, U1.12
INTFC_NC7: J51.6, U20.12
INTFC_NC8: J51.8, U20.11
INTFC_SWDCLK: J3.4, TP2.P$1, U1.10
INTFC_SWDCLK1: J13.4, TP4.P$1, U10.10
INTFC_SWDCLK2: J35.4, TP6.P$1, U15.10
INTFC_SWDCLK3: J51.4, TP8.P$1, U20.10
INTFC_SWDIO: J3.2, TP1.P$1, U1.13
INTFC_SWDIO1: J13.2, TP3.P$1, U10.13
INTFC_SWDIO2: J35.2, TP5.P$1, U15.13
INTFC_SWDIO3: J51.2, TP7.P$1, U20.13
LED_HID: D2.C, U1.30
LED_HID1: D8.C, U10.30
LED_HID2: D14.C, U15.30
LED_HID3: D20.C, U20.30
LED_MSD: D1.C, U1.29
LED_MSD1: D7.C, U10.29
LED_MSD2: D13.C, U15.29
LED_MSD3: D19.C, U20.29
LED_UART: D3.C, U1.31
LED_UART1: D9.C, U10.31
LED_UART2: D15.C, U15.31
LED_UART3: D21.C, U20.31
unnamed: D1.A, R1.1
unnamed: D2.A, R2.1
unnamed: D3.A, R3.1
unnamed: J1.B5, R6.2
unnamed: J1.A5, R7.2
unnamed: D5.A, R5.1
unnamed: D4.A, R4.1
unnamed: D6.4, R16.1
unnamed: D6.6, R18.1
unnamed: R11.1, U1.14
unnamed: J10.B5, R27.2
unnamed: TGT_SWD_CLK.1, U1.26
unnamed: C8.1, U1.17, X1.P1
unnamed: C10.2, U2.XI, Y1.P$2
unnamed: C11.2, U2.XO, Y1.P$1
unnamed: C9.1, U1.18, X1.P3
unnamed: J10.A5, R28.2
unnamed: TGT_BOOT.1, U1.9
unnamed: R9.1, U10.14
unnamed: C37.1, U10.17, X2.P1
unnamed: C38.1, U10.18, X2.P3
unnamed: C21.2, U6.XI, Y2.P$2
unnamed: C22.2, U6.XO, Y2.P$1
unnamed: D7.A, R8.1
unnamed: D8.A, R22.1
unnamed: D9.A, R24.1
unnamed: D10.A, R25.1
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

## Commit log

2019-09-13 progress commit
    got a lot of routing done, but more to do
    [Artembed.brd, Artembed.sch]
2019-09-16 Back up small form factor
    Moving to a more prototyping friendly large form factor for now
    [Artembed_SMALL.brd, Artembed_SMALL.sch]
2019-09-16 Remove board to start fresh
    [Artembed.brd]
2019-09-17 Pre proto review
    Waiting on XTAL footprint update from Eli
    [Artembed.brd, Artembed.sch]
2019-09-17 Update XTAL from Eli
    [Artembed.brd, Artembed.sch]
2019-09-19 proto review revisions, panelized, cammed
    [Artembed-Panel.GBL, Artembed-Panel.GBO, Artembed-Panel.GBP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]
2019-09-25 panelized + cammed
    [Artembed-Panel.GBL, Artembed-Panel.GBO, Artembed-Panel.GBP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]
2020-02-29 remove old stuff
    [Artembed-Panel.GBL, Artembed-Panel.GBO, Artembed-Panel.GBP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]
2020-02-29 initial commit of v02 schematic
    [Artembed.sch]
2020-03-02 work check 03/02
    [Artembed.brd, Artembed.sch]
2020-03-03 finished routing camera
    [Artembed.brd]
2020-03-03 routed gpio
    [Artembed.brd, Artembed.sch]
2020-03-03 ground purs and all airwires gone
    [Artembed.brd, Artembed.sch]
2020-03-04 added top silkscreen
    [Artembed.brd, Artembed.sch]
2020-03-04 add info silk, ran checklist
    [Artembed.brd, Artembed.sch, Board_Design_Checklist.xls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]
2020-03-04 generated v02 gerbers
    [Artembed.GBL, Artembed.GBO, Artembed.GBP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]
2020-03-11 generate bom csv
    [bom_output.csv]
2020-03-12 lay out labels for build sheet
    [Artembed.brd]
2020-05-28 clean slate for v03
    - renamed to ArtemisDevKit
    - renamed parts library
    - removed old gerber files
    - removed old BOM
    - added .DS_Store to .gitignore for MacOS
    [Artembed.GBL, Artembed.GBO, Artembed.GBP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]
2020-05-28 initial changes for v03
    - moved Apollo3 reset (TGT_RESET) to TARGET_NRESET on interface chip (pin c1)
    - moved TGT_BOOT to pin e30 (pad 9) of the interface chip (still meant to be pulled low most of the time - just making provisions for software control / serial bootloader compatibility later)
    - removed test point on clock lines
    [ArtemisDevKit.brd, ArtemisDevKit.sch]
2020-05-28 board changes to match initial changes
    [ArtemisDevKit.brd, ArtemisDevKit.sch]
2020-05-29 update labels
    [ArtemisDevKit.brd, ArtemisDevKit.sch]
2020-06-01 connect PTB1 to PTC1
    PTB1 (pin 21 on the 32-pin QFN package) is for 'SW_RESET_BUTTON' in the DAPLink firmware - this is for detecting when the user wants to enter DAPLink maintenance mode
    PTC1 (pin 22 on the 32-pin package) is meant to actually control the reset line of the Artemis - this was the mistake that was fixed with a green-wire on the v02 prototype.
    The effect of this change is that the user can hold the Artemis reset line while plugging in the DK to enter maintenance mode where they can upgrade the interface firmware, and also that the Artemis will be automatically reset when drag+drop programming occurs
    [ArtemisDevKit.brd, ArtemisDevKit.sch]
2020-06-01 remove unused connectors from special parts library
2020-06-01 final touches for review
    - updated library in use for the interface chip
    - mitered jumper labels
    - approved / fixed all drc errors
    [ArtemisDevKit.brd, ArtemisDevKit.sch]
2020-06-01 rework TGT_RST routing
    just a minor optimization
    [ArtemisDevKit.brd]
2020-06-05 remove old buzzard libraries and delete old silk
    [ArtemisDevKit.brd, ArtemisDevKit.sch]
2020-06-05 vector font in .sch
    [ArtemisDevKit.sch]
2020-06-05 apply changes from proto review
    - labeled jumpers w/ matching names and description
    - labeled accelerometer axes (bottom)
    - increaded power trace widths to 24 mil
    - removed VUSB current limiting resistor
    - increased buzzard label sizes
    - added AP2112K 3.3V regulator (disconnected MKL26Z regulator output from 3.3V bus to avoid contention)
    - added product name on top silk
    - changed reset button to the tall smd version
    [ArtemisDevKit.brd, ArtemisDevKit.sch]
2020-06-05 update to use MKL26Z128VFM4 from SparkFun library
    [ArtemisDevKit.brd, ArtemisDevKit.sch]
2020-06-08 update eagle libraries in brd + sch
    [ArtemisDevKit.brd, ArtemisDevKit.sch]
2020-06-08 replace sparkfun logo in schematic
    [ArtemisDevKit.brd, ArtemisDevKit.sch]
2020-06-08 update eagle libs and add LED silk
    [ArtemisDevKit.brd, ArtemisDevKit.sch]
2020-06-08 add overbar to reset label
    [ArtemisDevKit.brd]
2020-06-08 add checklist tools
    [Board_Design_Checklist.xls]
2020-06-08 perform checklist for v03
    [Board_Design_Checklist_ArtemisDevKit_v03.xls]
2020-06-10 QC double check changes
    [ArtemisDevKit.brd, ArtemisDevKit.sch]
2020-06-19 assembly sheet cleanup
    [ArtemisDevKit.brd]
2020-06-24 shift USB-C connector down 50 mil
    this is to make it properly centered on the board
    purely aesthetic motivation, with copper changes
    [ArtemisDevKit.brd]
2020-06-24 shift tgt swd connector
    this centers the label between the labels for the mic and acc
    [ArtemisDevKit.brd]
2020-06-24 Dimensions for board layout
    As of 6/24/20
2020-07-07 address Pete's reviews
    - improve GND pour on lower layer
    - fix ERC errors (mismatched values, footprints)
    - add LED buzzard labels
    - fix version in copper and schematic
    [ArtemisDevKit.brd, ArtemisDevKit.sch]
2020-07-07 update silkscreen
    [ArtemisDevKit.brd, ArtemisDevKit.sch]
2020-07-07 add test points for interface JTAG
    [ArtemisDevKit.brd, ArtemisDevKit.sch]
2020-07-07 fix camera connector
    [ArtemisDevKit.brd, ArtemisDevKit.sch]
2020-07-08 final design checklist
    -removed I2C PU resistors
    - switched bubble labels to UPPER CASE
    - ran checklist
    [ArtemisDevKit.brd, ArtemisDevKit.sch, Board_Design_Checklist_Artemis Dev Kit_v10.xls]
2020-07-08 reorganize checklist
    [Board_Design_Checklist_Artemis Dev Kit_v10.xls]
2020-07-08 remove VIN maximum
    [ArtemisDevKit.sch]
2020-07-10 panelize + CAM v10
    [ArtemisDevKit-Panel.brd]
2020-07-10 fix crooked frame on panel
    [ArtemisDevKit-Panel.brd]
2020-07-10 CAM for v10
    [ArtemisDevKit-Panel.GBL, ArtemisDevKit-Panel.GBO, ArtemisDevKit-Panel.GBP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]
2020-07-10 regenerate gerbers
    fixes crooked silk on the power output pins
    [ArtemisDevKit-Panel.brd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]
2020-07-14 replace 8+4 smd headers with 12
    [ArtemisDevKit.brd, ArtemisDevKit.sch]
2020-07-15 move an ugly trace
    [ArtemisDevKit.brd]
2020-07-15 approve drc errors
    [ArtemisDevKit.brd]
2020-07-15 generate gerbers
    [ArtemisDevKit-Panel.brd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]
2020-08-17 Update ArtemisDevKit.brd
    Added measurements for components to dimensions layer
    [ArtemisDevKit.brd]
2020-10-14 Add graphical datasheet and func. block diagram
    Add graphical datasheet and board functional block diagram for Artemis DK

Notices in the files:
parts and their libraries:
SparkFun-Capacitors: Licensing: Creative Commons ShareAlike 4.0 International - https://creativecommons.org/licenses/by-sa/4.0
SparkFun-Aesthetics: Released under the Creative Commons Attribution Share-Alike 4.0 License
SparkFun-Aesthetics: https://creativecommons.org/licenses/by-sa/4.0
